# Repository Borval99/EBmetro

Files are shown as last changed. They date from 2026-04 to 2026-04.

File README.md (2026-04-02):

# EBmetro

## Descrizione

Il progetto riguarda la ricostruzione di un **misuratore di campi elettrici e magnetici (EBmetro)** ideato dal Prof. Francesco Dalla Valle.

Lo strumento è stato progettato per rendere **misurabili e osservabili**:

* intensità del campo elettrico e magnetico
* direzione
* verso

con l’obiettivo di fornire un supporto concreto alla comprensione dell’elettromagnetismo.

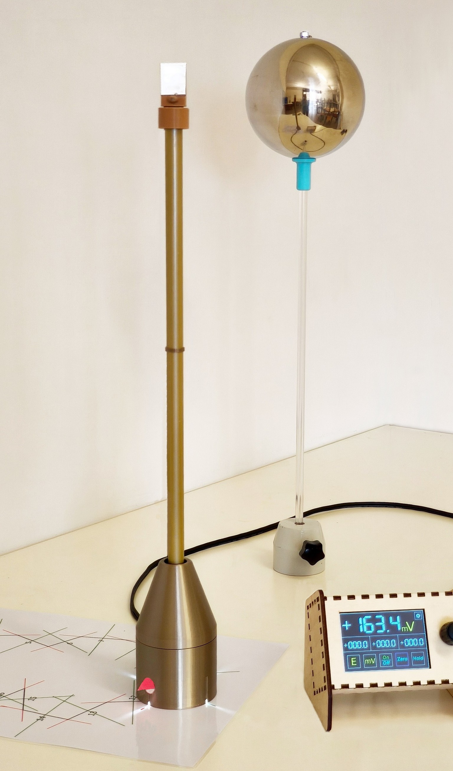
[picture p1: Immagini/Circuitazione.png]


---

## Obiettivo

L’EBmetro permette di verificare sperimentalmente:

* la circuitazione del campo elettrico lungo una linea chiusa
* la circuitazione del campo magnetico
* il fenomeno dell’induzione elettromagnetica

rendendo osservabili in modo diretto le prime tre equazioni di Maxwell.

---

## Struttura della repository

### /3D Model

Contiene i modelli dei case utilizzati per ospitare il microcontrollore e la scheda di acquisizione.

Sono presenti due principali varianti:

* versione per stampa 3D
* versione per taglio laser

La versione realizzata tramite intaglio laser consente una produzione più rapida e semplificata.

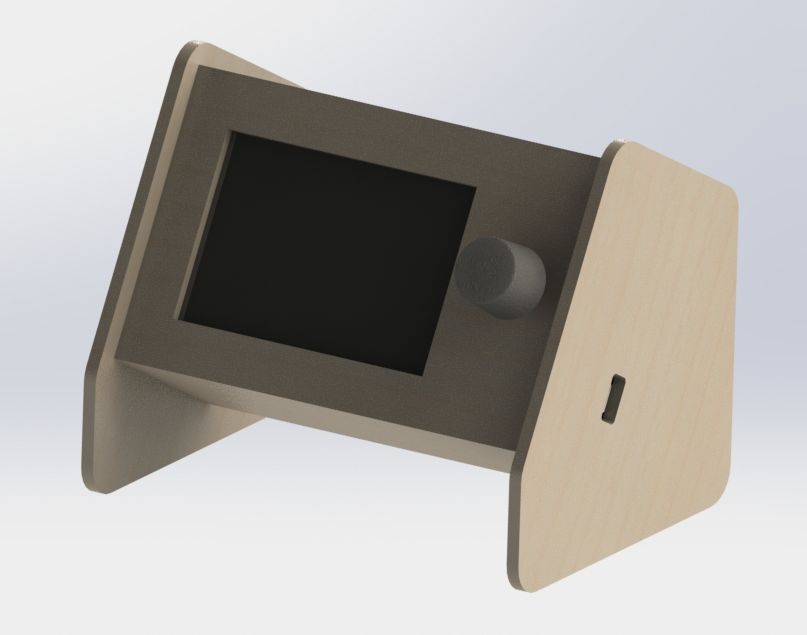
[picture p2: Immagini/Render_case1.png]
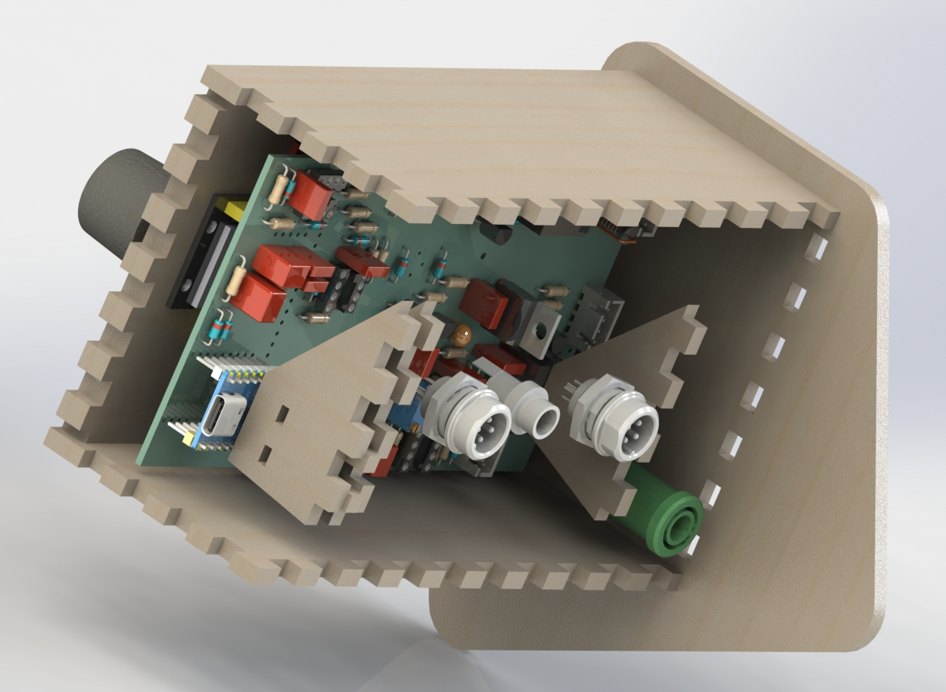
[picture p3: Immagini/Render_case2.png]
 

---

### /EBmetro

Contiene l’implementazione completa del dispositivo:

* schemi elettronici
* PCB
* firmware

Dove sono presenti le schede per l'EBmetro e per la base dell'EBmetro.

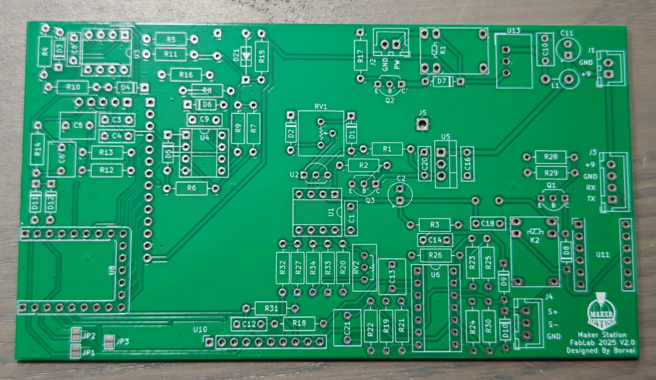
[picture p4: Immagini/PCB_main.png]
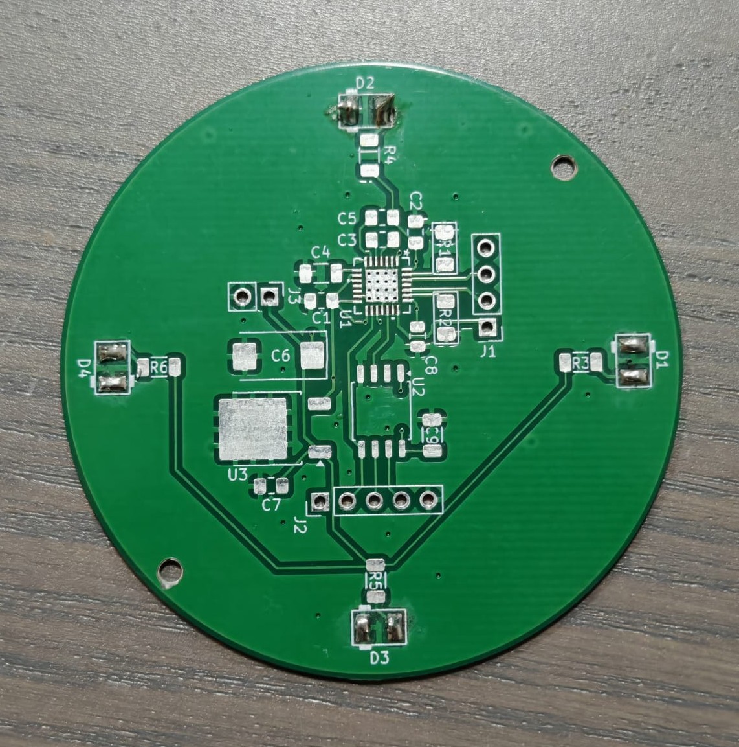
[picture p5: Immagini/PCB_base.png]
 

---

### /generatore

Contiene lo sviluppo di un generatore di rampe di corrente:

* schema elettronico
* firmware

Il generatore è in grado di fornire correnti fino a 30 A ed è utilizzato per pilotare bobine di Helmholtz.
Questo consente di generare campi magnetici controllati e misurare, tramite il sensore (“manico”), l’andamento della corrente indotta in un avvolgimento di dimensioni variabili.

---

## Descrizione del funzionamento

Il dispositivo consente la misura del campo elettrico o magnetico in funzione:

* della testina installata
* delle impostazioni software

L’elemento principale è una **testina rotante** dotata di contatti in oro, che ruota sul proprio asse.

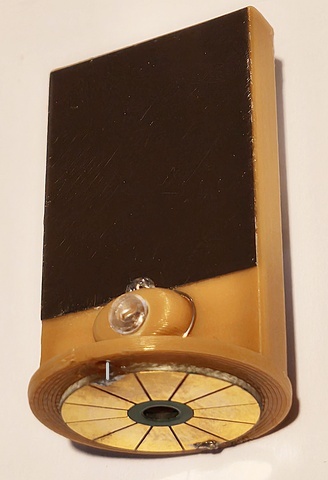
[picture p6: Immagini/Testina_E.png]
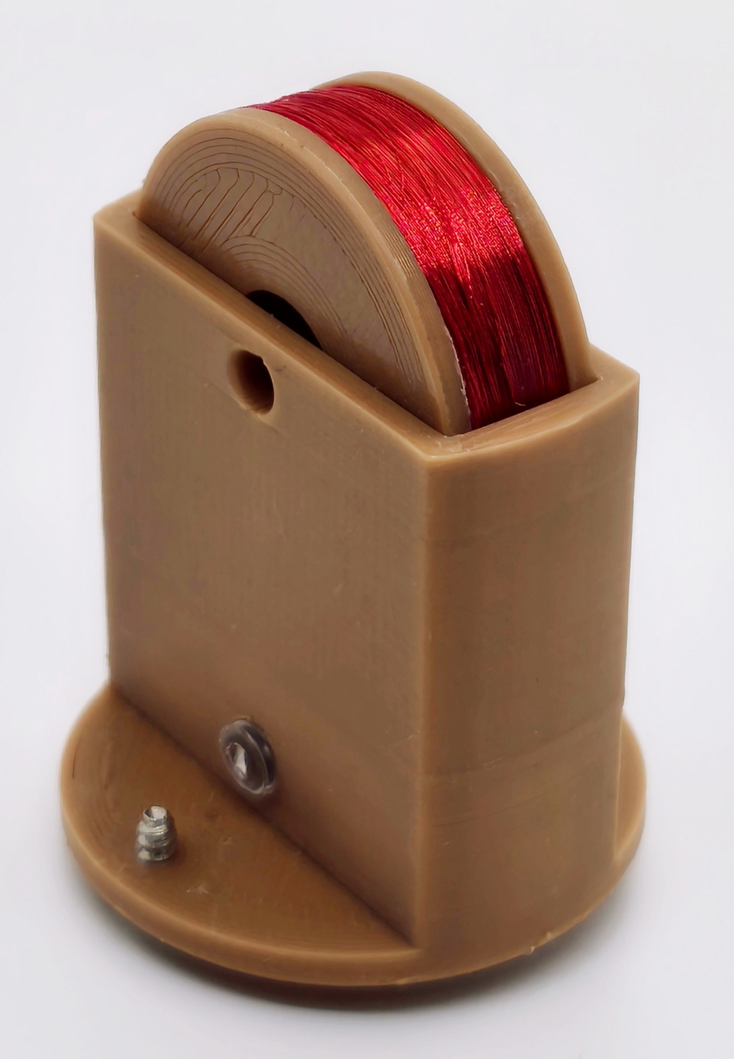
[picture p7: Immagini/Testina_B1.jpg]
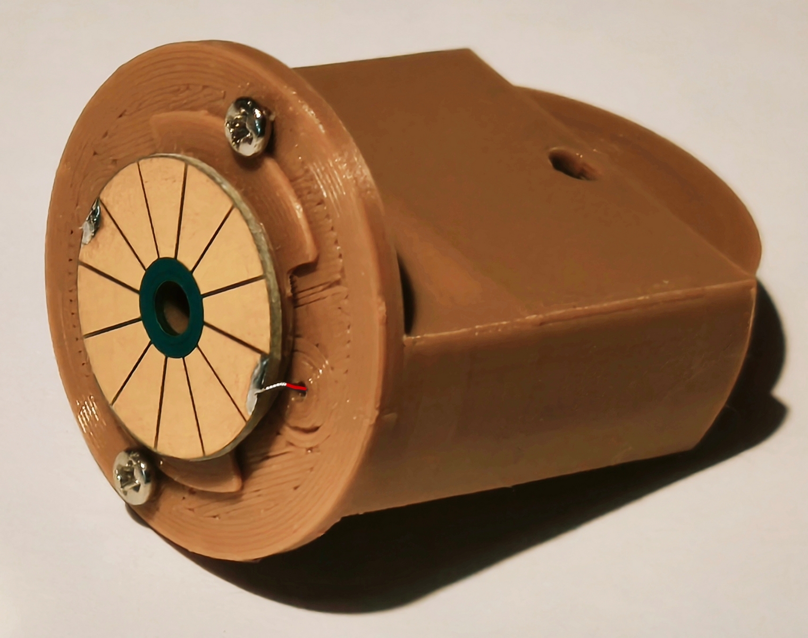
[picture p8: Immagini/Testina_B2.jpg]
  

I contatti sono stati realizzati tramite PCB, HASL con placcatura.

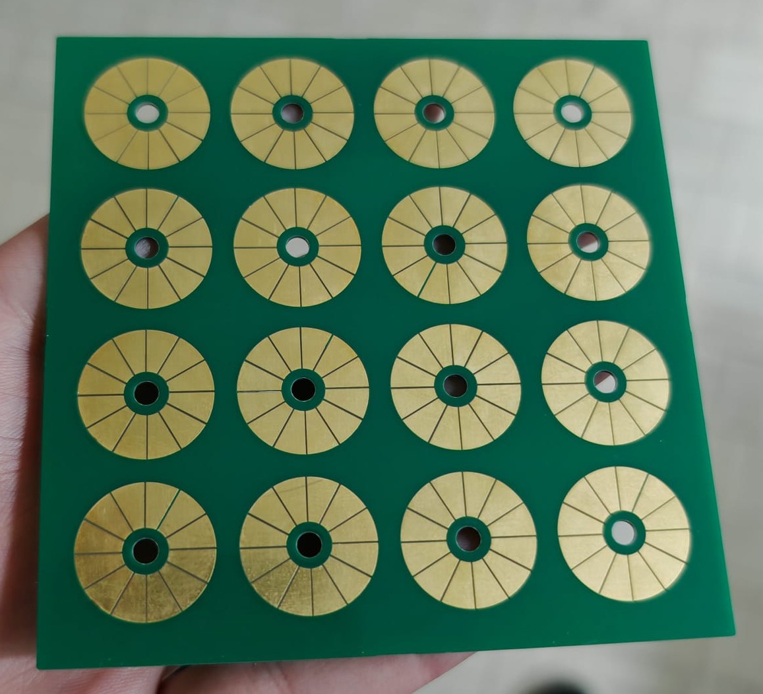
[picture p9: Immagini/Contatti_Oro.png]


Durante la rotazione, la testina entra in contatto con due **contatti striscianti**, permettendo l’acquisizione del segnale.

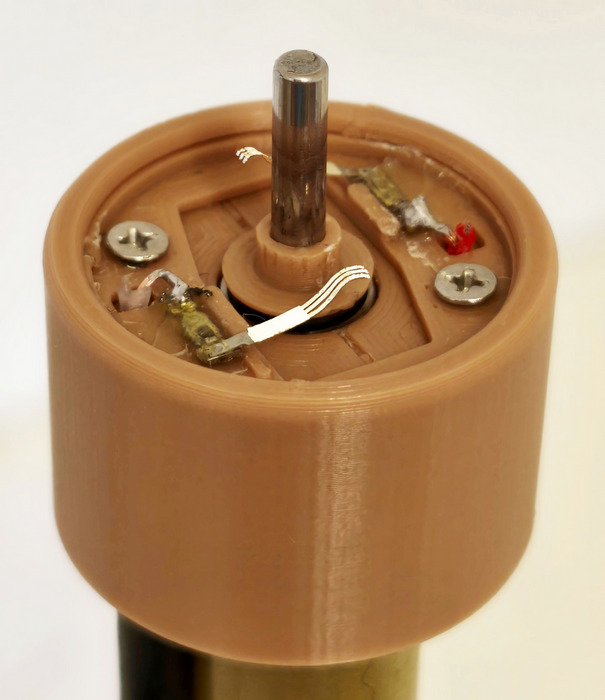
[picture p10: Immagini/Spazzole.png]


L’elaborazione del segnale avviene in un’unità separata dalla base, al fine di ridurre le interferenze sulla misura.

Nella base dell’EBmetro è possibile integrare:

* un motore brushless
* oppure un motore passo-passo

entrambi controllati da un microcontrollore ATtiny85 posizionato sotto la struttura.

L'EBmetro ha inoltre un Goniometro sulla propria base.

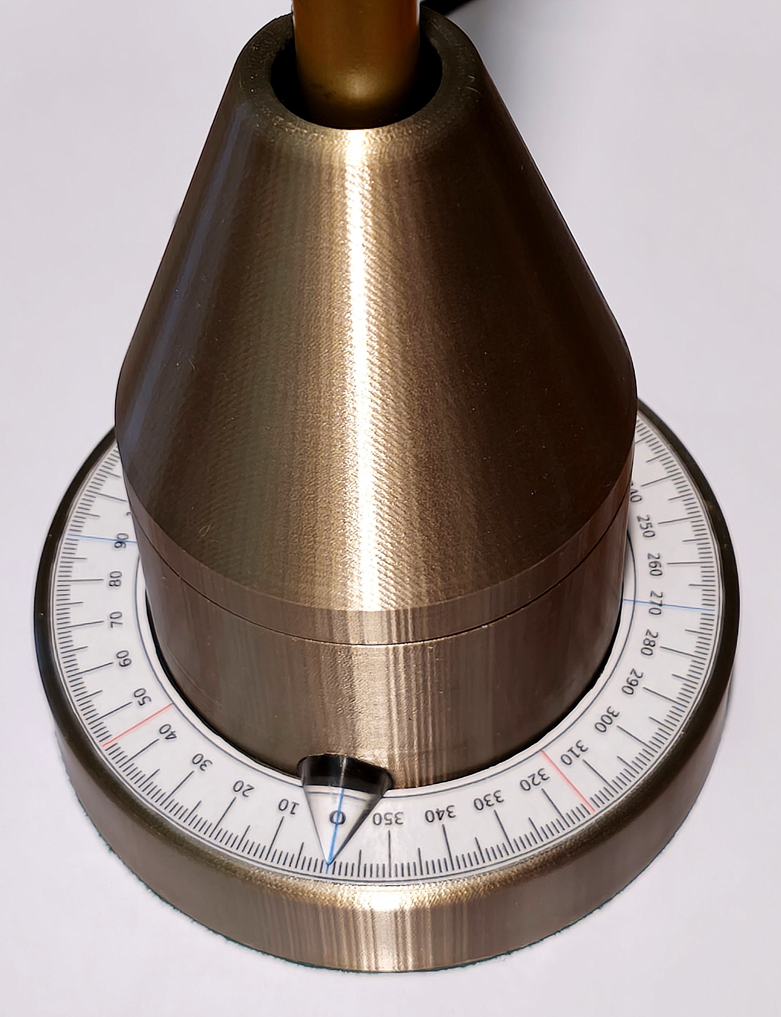
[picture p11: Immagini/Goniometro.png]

---

## Crediti

Ideato dal:

* Prof. Francesco Dalla Valle
* Prof. Giacomoni
* Prof. Cortesi

Sviluppo di questa versione:

* Enzo Cortesi
* Ing. Valerio Borghi
* FabLab Maker Station Bassa Romagna

---

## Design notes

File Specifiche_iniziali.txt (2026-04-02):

Filo:
Limitazione della corrente : Passo 2A, Max 30A (Passi con stabilizzazione Led Blink)
Tensione no limiti

Rampe:
Limitatore di corrente Fisso a 15A
Regolo in tensione 2-15V passo di massimo che si puo avere (Da stabilire all'inizio)
Vogliamo poter leggere corrente e tensione, realtime max min per ogni rampa

Onda trapezioidale, _/-\_ t1=t3=5s t2=t4=0.5s-5s
da ripetere 5 cicli alla pressione

Display 1.8p 128x160 Driver:st7735

Modalità:
-Filo
-Rampa
-Calibrazione? oppure settings in ogni pagina

Modaità Filo:
Mostra Tensione, Corrente
Passo attuale, passo prima e passo dopo
Cambio Modalità
Settings?

Modalità Rampe:
Mostra Tensione, Corrente, Max Min per Runtime
Onda Trapezoidale 
Tempi sotto l'onda, modificabili lampeggianti
Start
Un mini grafico della tensione? magari piu avanti

Generatore Classico: 
Dobbiamo mettere il display esterno,
Dia un impulso della Rampa al Misuratore della FEM

Misuratore della FEM:
Letture di qualche micro 
Schermo su cui scriverle
Offset Automatico / Manuale
Lettura precisa, accurato?

EBmetro
Alimentazione motore passo passo 20 step con driver
arduino nano 
Letture a mV

Misuratore di cariche

A parte a batterie 
Circuito campo elettrico

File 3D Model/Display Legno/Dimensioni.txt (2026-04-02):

"WFront"= 140mm
"HFront"= 80mm
"DFront"= 4mm
"WLeft"= 50mm
"HLeft"= 80mm
"DLeft"= 4mm
"WTop"= 140mm
"HTop"= 50mm
"DTop"= 4mm
"N_Denti_W"= 10
"N_Denti_H"= 7
"N_Denti_D"= 4
"HDistDenti"= "HFront" / "N_Denti_H"
"WDistDenti"= "WFront" / "N_Denti_W"
"DDistDenti"= "WLeft" / "N_Denti_D"
"HDenti"= "HDistDenti" / 2
"WDenti"= "WDistDenti" / 2
"DDenti"= "DDistDenti" / 2
"WDisplay"= 95mm
"HDisplay"= 61mm
"CEnc"= 7mm
"Display_to_Enc_W"= 11.5 + "CEnc" / 2
"Display_to_Dx"= 32mm
"Display_to_Top"= 10mm
"Display_to_Enc_H"= 24 + "CEnc" / 2
"DMask"= 3mm

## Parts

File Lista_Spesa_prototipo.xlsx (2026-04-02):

Si = |  |  |  | Lista della spesa
No = |  | Roba da compare al tecnomat =
In Lab = |  | Roba da comprare =
 | Da Acquistare | Generatore
 |  | Nome | Quantità | SIGLA | Prezzo I.I. | Link Acquisto | Link Datasheet | Note | Totale
 |  | DC-DC Converter Principale | 1 | ap-d5830a | 35 | Aliexpress (https://it.aliexpress.com/item/1005006873314722.html) | Datasheet (https://amsanelectronics.com/product/step-down-800w-30a-buck-converter-power-supply-penurun-tegangan-dc/) |  | 35
 |  | Alimentatore 24V 20A | 1 | RND 315-00017 | 109.8 | Distrelect (https://www.distrelec.it/it/alimentatore-montato-su-guida-din-ac-dc-94-24v-20a-480w-regolabile-rnd-rnd-315-00017/p/30151537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) | Datasheet (https://docs.rs-online.com/ba42/A700000011111373.pdf) | Era quello che costava meno | 109.8
 |  | Case PC + 3 ventole | 1 |  | 62.5 | Amazon (https://www.amazon.it/Mars-Gaming-MC-MASTER-Metal-Mesh-Ultrasilenziose/dp/B0BM4DSWJX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) |  | Da decidere | 62.5
 |  | Samd 21 Qt Py | 1 | Samd21 | 16 | Amazon (https://www.amazon.it/Adafruit-QT-Py-Scheda-sviluppo/dp/B09GZZF7BY?__mk_it_IT=%C3%85M%C3%85%C5%BD%C3%95%C3%91) |  |  | 16
 |  | MCP4725 | 1 | MCP4725 | 3 | Amazon (https://www.amazon.it/Jopto-Risoluzione-Fornitura-Compatibile-Raspberry/dp/B096Z6F4FB) | Datasheet (https://ww1.microchip.com/downloads/en/devicedoc/22039d.pdf) |  | 3
 |  | Connettore alta Potenza SA50 Pannello | 3 | SA50 Pannello | 3.14 | Aliexpress (https://it.aliexpress.com/item/1005005223111889.html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) | Datasheet (https://www.anen-connector.com/multipole-power-connectors-sa50sa502-2-product/) |  | 9.42
 |  | Pin per Connettore alta Potenza SA50 | 3 | SA50 PIN AWG6 | 0.6954 | CS (https://www.cselettronica.net/elettronica/connessione/conn-sa50-sb50-/pa1319-contatto-awg6-per-sa120.1.1.2444.gp.28132.uw) | Datasheet (https://www.anen-connector.com/multipole-power-connectors-sa50sa502-2-product/) |  | 2.0862
 |  | Connettore Display GX12-5Pin Maschio | 2 | GX12-5 | 0.7 | Amazon (https://www.amazon.it/QitinDasen-Aviazione-Connettore-Protettore-Cacciavite/dp/B07Y9VL1CT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) | Datasheet (https://renhotecpro2.b-cdn.net/wp-content/uploads/2022/01/GX-Series-Aviation-Connectors-Presentation-1.pdf) | Ki 8 +8 | 1.4
 |  | Resistenza shunt 40A 75mA | 1 | FL-2C 40A | 4.6 | Ebay (https://www.ebay.it/itm/164377654976?itmmeta=01J457QHX240EEKFACPEP4HRY8) |  | Sono indeciso tra 30A e 50A | 4.6
 |  | Ventole per pc | 2 |  | 5.5 | Amazon (https://www.amazon.it/Ventilatore-Silenzioso-Ottimizzata-Pressione-Confezione/dp/B07HC7P3HJ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) |  | Da decidere in base al case | 11
 |  | DC-DC Alimentazioni secondarie | 1 | LM2596 | 4.3 | CS (https://www.cselettronica.net/elettronica/alimentazione/convertitori-dc-dc/uscita-regolabile/2846-modulodcdc-dc-dc-uscita-1-5-35v-3a.1.1.2507.gp.22213.uw) |  |  | 4.3
 |  | Convertitore ADC 1115 | 1 | ADC1115 | 5.5 | Amazon (https://www.amazon.it/AZDelivery-Convertitore-ADS1115-Raspberry-Gratuito/dp/B07QHWLTTS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) | Datasheet (https://cdn-shop.adafruit.com/datasheets/ads1115.pdf) |  | 5.5
 |  | LMC6484 Quad OpAmp | 1 | LMC6484 | 2.5986 | CS (https://www.cselettronica.net/elettronica/attivi/integrati/integrati-a-z/integrati-lmc/integrato-lmc6484in-nopb.1.1.311.gp.3039.uw) | Datasheet (http://www.ti.com/lit/ds/symlink/lmc6484.pdf) |  | 2.5986
 |  | Sensore di Temperatura | 3 | LM35D | 1.5982 | CS (https://www.cselettronica.net/elettronica/attivi/integrati/integrati-a-z/integrati-lm/integrato-lm35dz-nopb.1.1.312.gp.11687.uw) | Datasheet (http://www.ti.com/lit/ds/symlink/lm35.pdf) |  | 4.7946
 |  | Componentistica varie | 1 |  | 15 | CS |  |  | 15
 |  | Relè per attivare/disattivare il DCDC | 1 | SYS1 | 0.7442 | CS (https://www.cselettronica.net/elettronica/commutazione/rele-elettromeccanici/rele-con-bobina-a-c-c-/bobina-a-5vdc/1-scambio/sys1-rele-5vdc-1-scambio.1.1.867.g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) | Datasheet (https://www.sanyourelay.ca/public/products/pdf/SYS1.pdf) |  | 0.7442
 |  | BC547 per Relè | 1 | BC547 | 0.061 | CS (https://www.cselettronica.net/elettronica/attivi/transistor/transistor/transistor-bc-/transistor-bc547b.1.1.750.gp.7309.uw) | Datasheet (https://www.mouser.it/datasheet/2/308/1/BC550_D-2310266.pdf) |  | 0.061
 |  | Reference Voltage 2.5 V | 1 | LM336Z-2.5 | 0.6466 | CS (https://www.cselettronica.net/elettronica/attivi/integrati/integrati-a-z/integrati-lm/integrato-lm336z-2-5-nopb.1.1.312.gp.18601.uw) | Datasheet (https://www.ti.com/lit/ds/symlink/lm136-2.5-n.pdf?HQS=dis-dk-null-digikeymode-dsf-pf-null-wwe&ts=1722377945944) |  | 0.6466
 |  | Cavo unipolare 16mm^2 | 2 |  | 2.5 |  |  |  | 5
 |  | Capicorda A3M6 per 16mm^2 | 5 | A3M6 | 0.2684 | CS (https://www.cselettronica.net/elettronica/connessione/terminali/terminali-preisolati/capicorda/a3m6-capicorda-non-isolato-a-6-4-b-11-5.1.1.2359.gp.19857.uw) |  |  | 1.342
 |  | 0,5 Ohm 100W 5% | 2 | HSC100R47J | 4 | Amazon (https://www.amazon.it/ETOPARS-Resistore-Alluminio-Resistenza-Adattatore/dp/B0BWXLP8VQ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) |  | Su Amazon costano la metà | 8
 |  | 0,10 Ohm 100W 5% | 3 | HSC100R10J | 4 | Amazon (https://www.amazon.it/PATIKIL-Alluminio-Involucro-Alloggiamento-Resistenza/dp/B0C6F3RVC3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) |  | Su Amazon costano la metà | 12
 |  | Dissipatore 250*70*28 | 2 |  | 17.995 | CS (https://www.cselettronica.net/elettronica/attivi/accessori/dissipatori/diss-a-pettine/sk4975sa-dissipatore-250x28-l-75-nero.1.1.114.gp.25388.uw) | Datasheet (https://www.fischerelektronik.de/web_fischer/en_GB/VA/SK4975SA/datasheet.xhtml?branch=heatsinks) |  | 35.99
 |  | Pasta Termica nano-grease 3g | 1 |  | 3.599 | CS (https://www.cselettronica.net/elettronica/attivi/accessori/paste-termoconduttive/pasta-termica-nano-grease-3gr.1.1.23.gp.11730.uw) |  |  | 3.599
 |  | Scheda PCB / Millefori 70*50 | 1 |  | 1 | CS |  |  | 1
 |  |  |  |  |  |  |  |  | 0
 |  | TOTALE |  |  |  |  |  |  | 355.3822
 |  | Wire
 |  | Nome | Quantità | SIGLA | Prezzo | Link Acquisto | Link Datasheet | Note | Totale
 |  | Tubo in ferro filettato | 3 |  | 7.9 | Tecnomat (https://www.tecnomat.it/it/tubo-ferro-zincato-3-8-100-cm-10008368/) |  |  | 23.7
 |  | Curve in ferro | 3 |  | 1.07 | Tecnomat (https://www.tecnomat.it/it/raccordo-ghisa-90-gomito-ff3-8-10035679/) |  |  | 3.21 | DA RIVEDERE
 |  | Connettore alta Potenza SA50 | 1 | SA50 | 0.9028 | CS (https://www.cselettronica.net/elettronica/connessione/conn-sa50-sb50-/sa50-supporto-per-contatti-2-vie-rosso-con-viti.1.1.2444.gp.21128.uw) | Datasheet (https://www.anen-connector.com/multipole-power-connectors-sa50sa502-2-product/) |  | 0.9028
 |  | Pin per Connettore alta Potenza SA50 | 1 | SA50 PIN AWG6 | 0.6954 | CS (https://www.cselettronica.net/elettronica/connessione/conn-sa50-sb50-/pa1319-contatto-awg6-per-sa120.1.1.2444.gp.28132.uw) | Datasheet (https://www.anen-connector.com/multipole-power-connectors-sa50sa502-2-product/) |  | 0.6954
 |  | Cavo unipolare 16mm^2 | 8 |  | 2.5 |  |  |  | 20
 |  | Struttura | 1 |  | 40 |  |  | Da decidere | 40
 |  | Gancio SA50 | 1 | SA50 Gancio | 1.0004 | CS (https://www.cselettronica.net/elettronica/connessione/conn-sa50-sb50-/pa112g1-maniglia-per-connettore-sa50-rossa-con-viti.1.1.2444.gp.28128.uw) | Datasheet (https://www.anen-connector.com/multipole-power-connectors-sa50sa502-2-product/) |  | 1.0004
 |  |  |  |  |  |  |  |  | 89.5086
 |  | Totale
 |  | Display
 |  | Nome | Quantità | SIGLA | Prezzo | Link Acquisto | Link Datasheet | Note | Totale
 |  | Display LCD tft 4'' | 1 |  | 20 | Amazon (https://www.amazon.it/LAFVIN-4-0-inch-TFT-Compatible/dp/B0CQ87KN3Q?__mk_it_IT=%C3%85M%C3%85%C5%BD%C3%95%C3%91) |  |  | 20
 |  | Arduino MKR Zero | 1 | Arduino MKR Zero | 20 | Arduino Store (https://store.arduino.cc/collections/boards-modules/products/arduino-mkr-zero-i2s-bus-sd-for-sound-music-digital-audio-data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) | Datasheet (https://docs.arduino.cc/resources/datasheets/ABX00023-datasheet.pdf) | Si può cambiare con qualcosa da meno | 20
 |  | Modulo Encoder KY040 | 1 | KY040 | 2.0008 | CS (https://www.cselettronica.net/ky040-modulo-encoder.1.0.2531.gp.23741.uw) |  |  | 2.0008
 |  | Scheda PCB / Millefori 70*50 | 1 |  | 1 | CS |  |  | 1
 |  | Connettore Display GX12-5Pin Maschio | 1 | GX12-5 | 0.7 | Amazon (https://www.amazon.it/QitinDasen-Aviazione-Connettore-Protettore-Cacciavite/dp/B07Y9VL1CT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) | Datasheet (https://renhotecpro2.b-cdn.net/wp-content/uploads/2022/01/GX-Series-Aviation-Connectors-Presentation-1.pdf) | Su Amazon costano la metà | 0.7
 |  | Connettore Display GX12-5Pin Femmina | 2 | GX12-5 | 0.7 | Amazon (https://www.amazon.it/QitinDasen-Aviazione-Connettore-Protettore-Cacciavite/dp/B07Y9VL1CT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) | Datasheet (https://renhotecpro2.b-cdn.net/wp-content/uploads/2022/01/GX-Series-Aviation-Connectors-Presentation-1.pdf) | Su Amazon costano la metà | 1.4
 |  | Cavo 5 poli Morbido | 2 |  | 2 |  |  | Da decidere | 4
 |  | Connettori in plastica per connesioni interne | 1 |  | 1 |  |  |  | 1
 |  | Manopola 22 più tappo blu | 1 |  | 1 | CS |  |  | 1
 |  | Totale |  |  |  |  |  |  | 51.1008
 |  | Manico
 |  | Nome | Quantità | SIGLA | Prezzo | Link Acquisto | Link Datasheet | Note | Totale
 |  | Connettore manico GX12-5Pin Maschio | 1 | GX12-5 | 0.7 | Amazon (https://www.amazon.it/QitinDasen-Aviazione-Connettore-Protettore-Cacciavite/dp/B07Y9VL1CT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) | Datasheet (https://renhotecpro2.b-cdn.net/wp-content/uploads/2022/01/GX-Series-Aviation-Connectors-Presentation-1.pdf) | Su Amazon costano la metà | 0.7
 |  | Connettore manico GX12-5Pin Femmina | 2 | GX12-5 | 0.7 | Amazon (https://www.amazon.it/QitinDasen-Aviazione-Connettore-Protettore-Cacciavite/dp/B07Y9VL1CT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) | Datasheet (https://renhotecpro2.b-cdn.net/wp-content/uploads/2022/01/GX-Series-Aviation-Connectors-Presentation-1.pdf) | Su Amazon costano la metà | 1.4
 |  | Cavo 5 poli Morbido | 3 |  | 2 |  |  | Da decidere | 6
 |  | Scheda PCB / Millefori 30*40 | 1 |  | 1 | CS |  |  | 1
 |  | Convertitore ADC 1115 | 1 | ADC1115 | 5.5 | Amazon (https://www.amazon.it/AZDelivery-Convertitore-ADS1115-Raspberry-Gratuito/dp/B07QHWLTTS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) | Datasheet (https://cdn-shop.adafruit.com/datasheets/ads1115.pdf) |  | 5.5
 |  | LMC6484 Quad OpAmp | 1 | LMC6484 | 2.5986 | CS (https://www.cselettronica.net/elettronica/attivi/integrati/integrati-a-z/integrati-lmc/integrato-lmc6484in-nopb.1.1.311.gp.3039.uw) | Datasheet (http://www.ti.com/lit/ds/symlink/lmc6484.pdf) | Per creare lo zero | 2.5986
 |  | Amplif da Banco AD623ANZ | 1 | AD623ANZ | 6.954 | CS (https://www.cselettronica.net/elettronica/attivi/integrati/integrati-a-z/integrati-ad/integrato-ad623anz.1.1.744.gp.23999.uw) | Datasheet (https://www.analog.com/media/en/technical-documentation/data-sheets/ad623.pdf) | Al posto di questo un adc che fa tutto ma costa 20 | 6.954
 |  | Teste di racambio del Manico | 3 |  | 10 |  |  | Non so quanto possano costare | 30
 |  | Arduino nano | 1 |  | 8 |  |  | Ci mettiamo un nano per ora | 8
 |  | Componentistica varie | 1 |  | 5 | CS |  |  | 5
 |  | Totale |  |  |  |  |  |  | 67.1526
 |  | Ebmetro
 |  | Nome | Quantità | SIGLA | Prezzo | Link Acquisto | Link Datasheet | Note | Totale
 |  | Arduino Nano | 1 |  | 10 | Arduino Store (https://store.arduino.cc/products/arduino-nano) | Datasheet (https://ww1.microchip.com/downloads/en/DeviceDoc/Atmel-7810-Automotive-Microcontrollers-ATmega328P_Datasheet.pdf) | Su Amazon costa meno | 10
 |  | Batterie al litio | 2 |  | 5 |  |  | Da decidere | 10
 |  | Circuito di ricarica | 1 |  | 3 |  |  | Da decidere | 3
 |  | Connettore manico GX12-5Pin Maschio | 2 | GX12-5 | 0.7 | Amazon (https://www.amazon.it/QitinDasen-Aviazione-Connettore-Protettore-Cacciavite/dp/B07Y9VL1CT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) | Datasheet (https://renhotecpro2.b-cdn.net/wp-content/uploads/2022/01/GX-Series-Aviation-Connectors-Presentation-1.pdf) | Su Amazon costano la metà | 1.4
 |  | Connettore manico GX12-5Pin Femmina | 2 | GX12-5 | 0.7 | Amazon (https://www.amazon.it/QitinDasen-Aviazione-Connettore-Protettore-Cacciavite/dp/B07Y9VL1CT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) | Datasheet (https://renhotecpro2.b-cdn.net/wp-content/uploads/2022/01/GX-Series-Aviation-Connectors-Presentation-1.pdf) | Su Amazon costano la metà | 1.4
 |  | Cavo 5 poli Morbido | 2 |  | 2 |  |  | Da decidere | 4
 |  | Convertitore ADC 1115 | 1 | ADC1115 | 5.5 | Amazon (https://www.amazon.it/AZDelivery-Convertitore-ADS1115-Raspberry-Gratuito/dp/B07QHWLTTS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) | Datasheet (https://cdn-shop.adafruit.com/datasheets/ads1115.pdf) |  | 5.5
 |  | Componentistica varie | 1 |  | 5 | CS |  |  | 5
 |  | Componentistica di Enzo | 1 |  | 50 | CS |  | Da decidere | 50 | Discutibili
 |  | Display tft 1,8'' con driver ST3735 | 1 |  | 8.052 | CS |  | Da decidere | 8.052
 |  | Totale |  |  |  |  |  |  | 98.352
 |  | Misuratore di Carche
 |  | Nome | Quantità | SIGLA | Prezzo | Link Acquisto | Link Datasheet | Note | Totale
 |  | Arduino Nano | 1 |  | 10 | Arduino Store (https://store.arduino.cc/products/arduino-nano) | Datasheet (https://ww1.microchip.com/downloads/en/DeviceDoc/Atmel-7810-Automotive-Microcontrollers-ATmega328P_Datasheet.pdf) | Su Amazon costa meno | 10
 |  | Batterie al litio | 2 |  | 5 |  |  | Da decidere | 10
 |  | Circuito di ricarica | 1 |  | 6 |  |  | Da decidere | 6
 |  | Convertitore ADC 1115 | 1 | ADC1115 | 5.5 | Amazon (https://www.amazon.it/AZDelivery-Convertitore-ADS1115-Raspberry-Gratuito/dp/B07QHWLTTS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) | Datasheet (https://cdn-shop.adafruit.com/datasheets/ads1115.pdf) |  | 5.5
 |  | Componentistica varie | 1 |  | 5 | CS |  |  | 5
 |  | Componentistica di Enzo | 1 |  | 30 | CS |  | Da decidere | 30
 |  | Display tft 1,8'' con driver ST3735 | 1 |  | 8.052 | CS |  | Da decidere | 8.052
 |  | Totale |  |  |  |  |  |  | 74.552
 |  | Totale di tutto |  |  |  |  |  |  | 736.0482
 |  | COMPONENTI DA PROVARE
 |  | Attiny85 module | 1 | ATTiny85 | 12 | Amazon (https://www.amazon.it/Aihasd-Digispark-Kickstarter-ATTINY85-sviluppo/dp/B07439SSQV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) |  |  | 12
 |  | Adattatori | 1 |  | 8 | Amazon (https://www.amazon.it/Gebildet-3-3V-5V-Convertitore-bidirezionale-confezione/dp/B07RY15XMJ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) |  |  | 8
 |  | RP2040 | 1 |  | 10 | Amazon (https://www.amazon.it/XTVTX-microcontrollore-RP2040-Zero-intestazione-applicazioni/dp/B0BCVW5YKK/) |  |  | 10

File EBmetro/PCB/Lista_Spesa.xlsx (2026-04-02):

Reference | Value | Qty
C1,C3,C4,C8,C9,C14,C15,C18 | 100n | 8
C2,C17 | 15u | 2
C5,C6,C7,C13,C19 | 1u | 5
C10,C11 | 1m | 2
C12 | 15n | 1
D1,D2,D3,D4,D5,D6,D7,D8,D9,D10,D11,D12 | 1N4148 | 12
DZ1 | 2.5V Zener 1N5222B | 1
J1,J2 | Conn_01x02 | 2
J3 | Conn_01x04 | 1
J4 | Conn_01x03 | 1
K1 | SYS1 | 1
K2 | TIANBO-HJR-4102-L | 1
Q1,Q2,Q3 | BC547B | 3
R1 | 2k4 | 1
R2,R18 | 100 | 2
R3 | 1k | 1
R4,R6,R8,R10 | 3.3K | 4
R5,R7,R9,R11 | 33k | 4
R12 | 330k | 1
R13,R14,R17,R29,RV1 | 10k | 5
R15 | 150 | 1
R16,R28 | 470 | 2
R19 | 220k | 1
R20,R21,R22,R23,R24,R26 | 45.3k, 1% | 6
R25 | 4.53k, 1% | 1
R27 | 15k | 1
R30 | 10M | 1
R31 | 18K | 1
U1,U3,U4,U6,U7 | MCP602 | 5
U2 | LM336Z25 | 1
U5,U9 | ~ | 2
U8 | RP2040-ZERO | 1
U10 | Adafruit ADS1115 | 1
U11 | Level Shifter CYT1076 | 1
U12 | Encoder KY-040 | 1

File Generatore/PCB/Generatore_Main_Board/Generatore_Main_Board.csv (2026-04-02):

Reference | Value
C1 | 100n
C2 | 10n
C3 | 100n
C4 | 10n
C5 | 100n
C6 | 10n
C7 | 100n
C8 | 100n
C9 | 100n
D1 | 1N4148
D2 | 1N4148
D3 | 1N4148
D4 | 1N4148
D5 | 1N4148
D6 | 1N4148
D7 | 1N4148
D8 | 1N4148
D9 | 1N4148
D10 | 1N4148
D11 | 1N4148
D12 | 1N4148
D13 | 1N4148
J1 | Conn_01x04
J2 | Conn_01x04
J3 | Conn_01x02
J4 | Conn_01x03
J5 | Conn_01x03
J6 | Conn_01x03
J7 | Conn_01x02
J8 | Conn_01x03
J9 | Conn_01x02
J10 | Conn_01x02
J11 | Conn_01x02
J12 | Conn_01x02
J13 | Presa IEC pannello
J14 | Alimentatore 230Vac/12Vdc
J15 | 13V_VDD_VENTOLE
J16 | Conn_01x02
K1 | SANYOU SYS1-S-112L
Q1 | BC547B
Q2 | 2N7000
Q3 | 2N7000
Q4 | 2N7000
Q5 | 2N7000
Q6 | BC547B
R1 | 4k7
R2 | 4k7
R3 | 4k7
R4 | 4k7
R5 | 4k7
R6 | 100R
R7 | 10k
R8 | 10k
R9 | 1k
R10 | 2k4
R11 | 27k
R12 | 3k
R13 | 100R
R14 | 100R
R15 | 14k7 1%
R16 | 14k7 1%
R17 | 45k3 1%
R18 | 45k3 1%
R19 | 4k7
R20 | 4k7
R21 | 4k7
R22 | 4k7
R23 | 10k
R24 | 1k2
R25 | 10k
R26 | 10k
RV1 | 10k
RV2 | 10k
U1 | Adafruit ADS1115
U2 | Adafruit ADS1115
U3 | Level Shifter CYT1076
U4 | Level Shifter CYT1076
U5 | MCP4725 breakout module
U6 | LM336Z5
U7 | LM35-LP
U8 | LMC6484
U9 | MCP602
U10 | LM336Z25
U11 | MCP602
U12 | RP2040-ZERO
U13 | DCDC_Converter 3,2-40V/1,25-35V

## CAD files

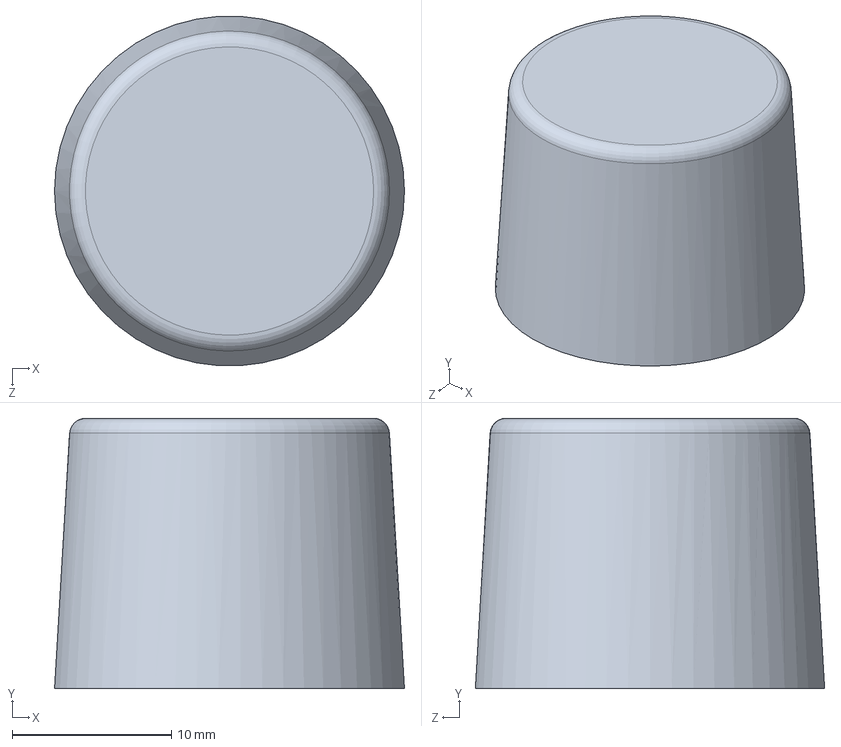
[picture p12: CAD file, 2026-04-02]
3D Model/Display Legno/Manopola.SLDPRT
22.0 x 17.0 x 22.0 mm

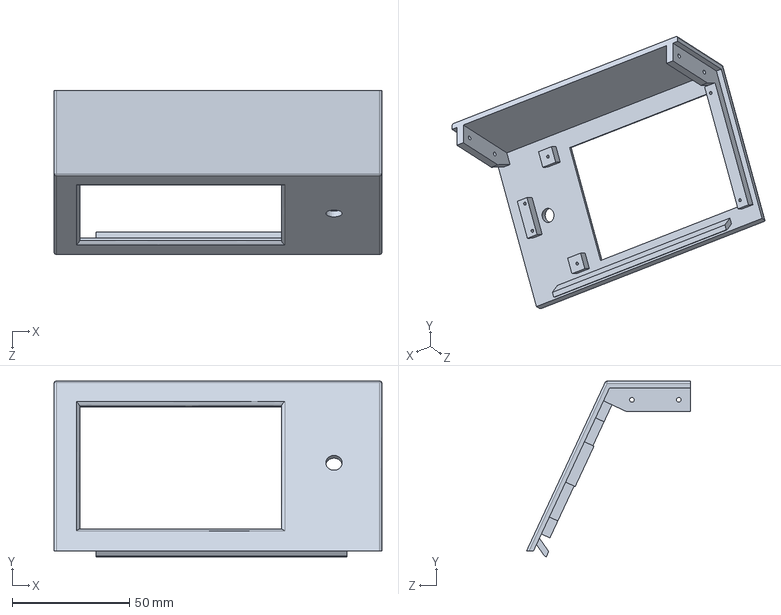
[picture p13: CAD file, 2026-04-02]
3D Model/Display/Case_Facciata.SLDPRT
140.0 x 75.0 x 70.0 mm

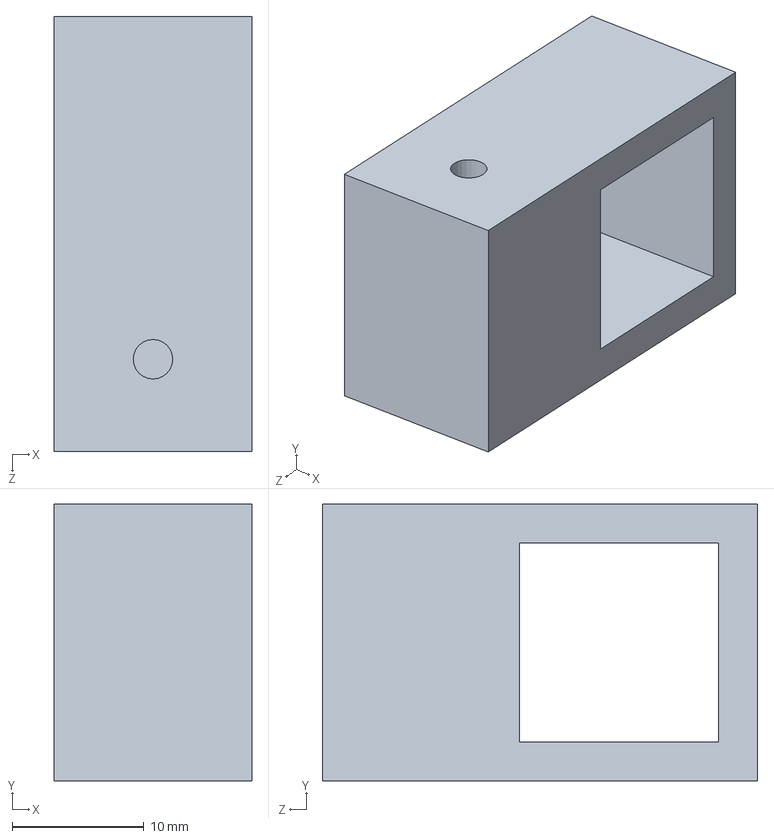
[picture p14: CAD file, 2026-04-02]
3D Model/Manico/STL/Supporto_1.SLDPRT
15.0 x 21.0 x 33.0 mm

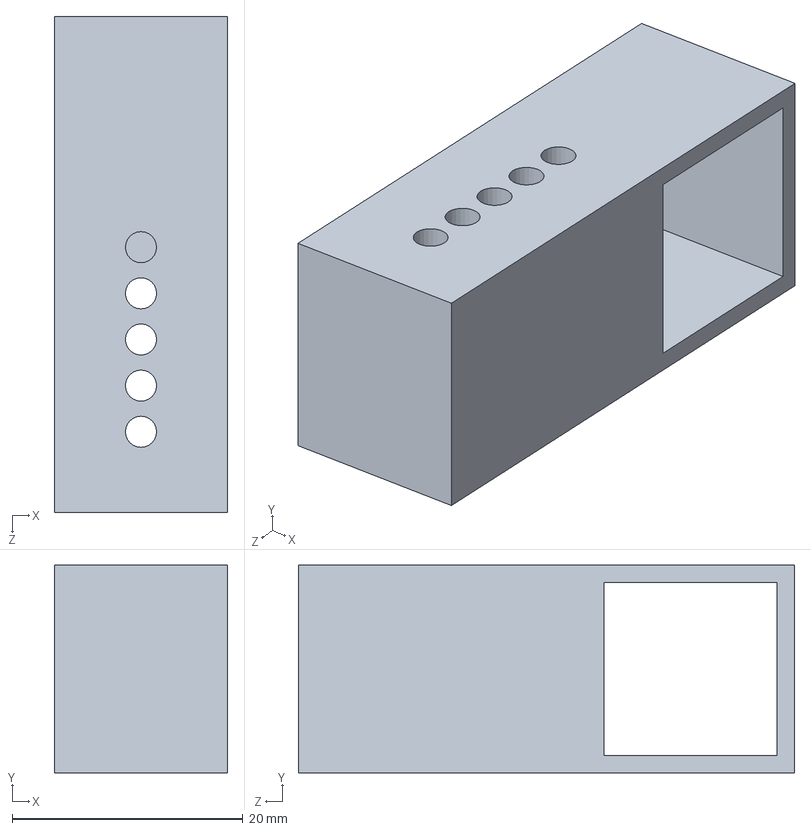
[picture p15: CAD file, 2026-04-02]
3D Model/Manico/Supporto_5.SLDPRT
15.0 x 18.0 x 43.0 mm

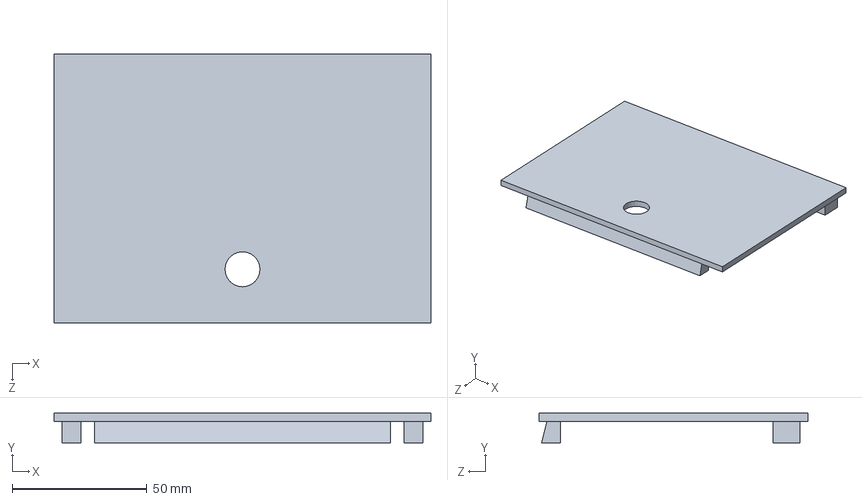
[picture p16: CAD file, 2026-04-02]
3D Model/Display/Case_Retro.SLDPRT
140.0 x 11.0 x 100.0 mm

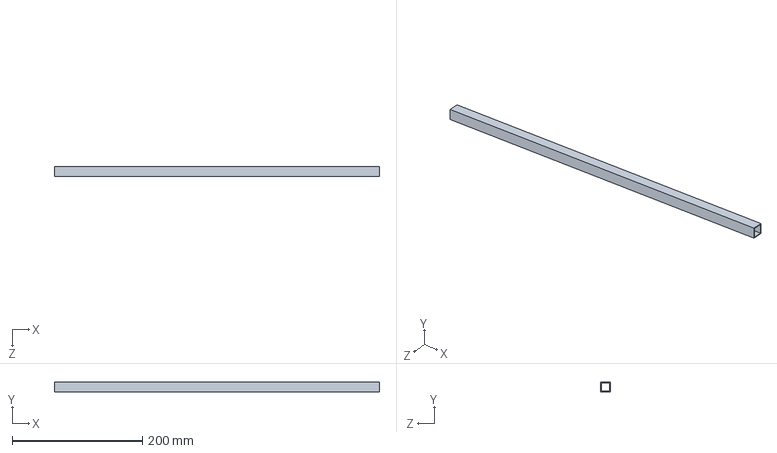
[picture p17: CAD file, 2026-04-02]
3D Model/Manico/Profilato_15_15.SLDPRT
500.0 x 15.0 x 15.0 mm

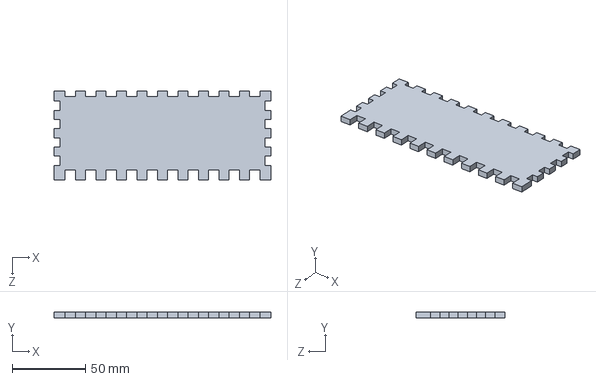
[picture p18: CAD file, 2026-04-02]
3D Model/Display Legno/Top.SLDPRT
148.0 x 4.00 x 61.0 mm

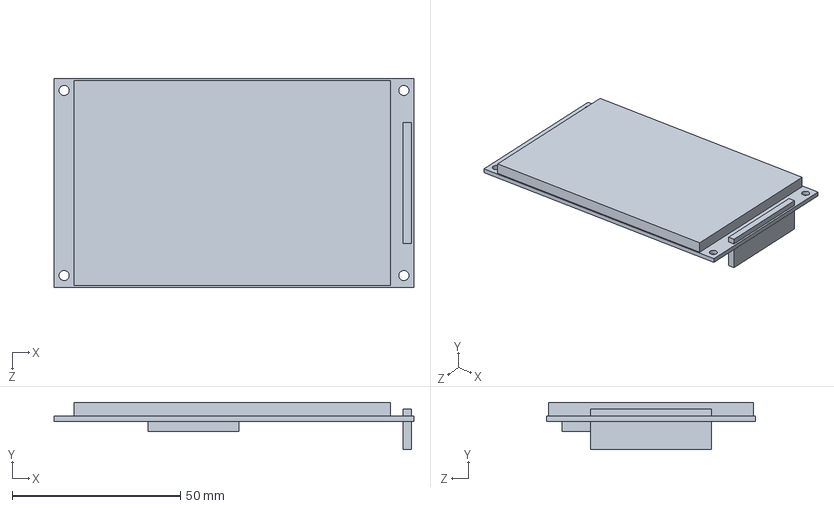
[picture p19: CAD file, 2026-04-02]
3D Model/Display/Display.SLDPRT
107.0 x 14.0 x 62.0 mm

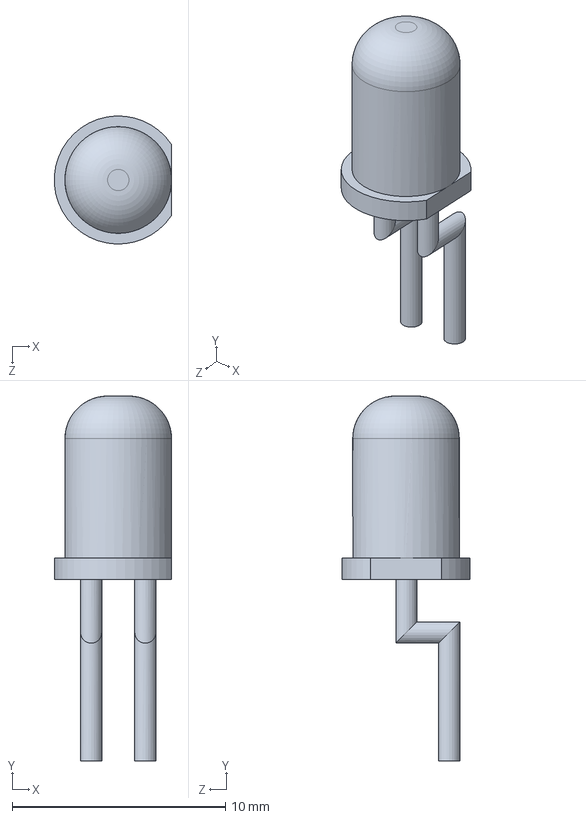
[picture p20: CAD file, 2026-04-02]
3D Model/EBmetro Base/LED.SLDPRT
5.49 x 17.1 x 6.00 mm

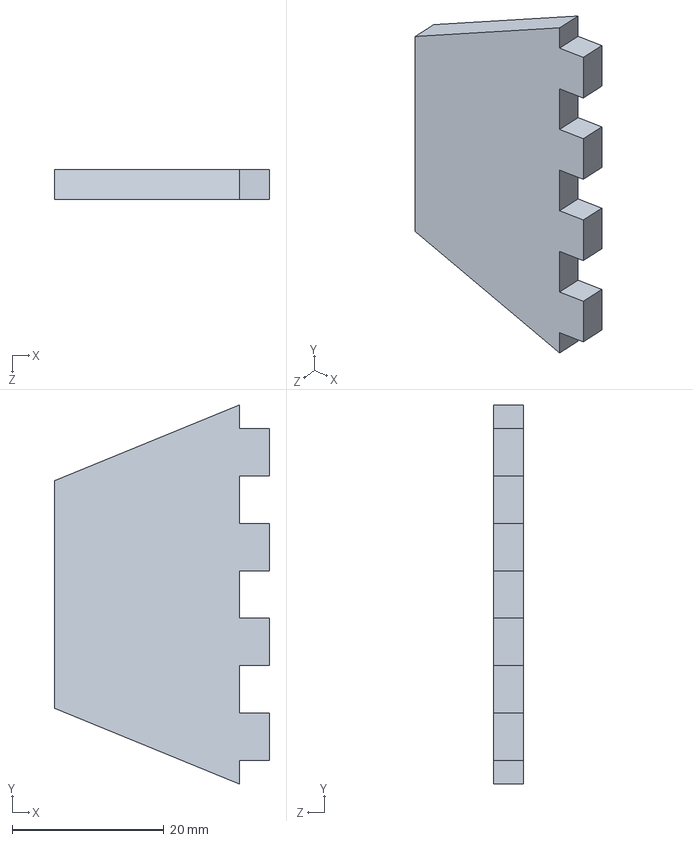
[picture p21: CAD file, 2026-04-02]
3D Model/Display Legno/Supporto.SLDPRT
28.4 x 50.0 x 4.00 mm

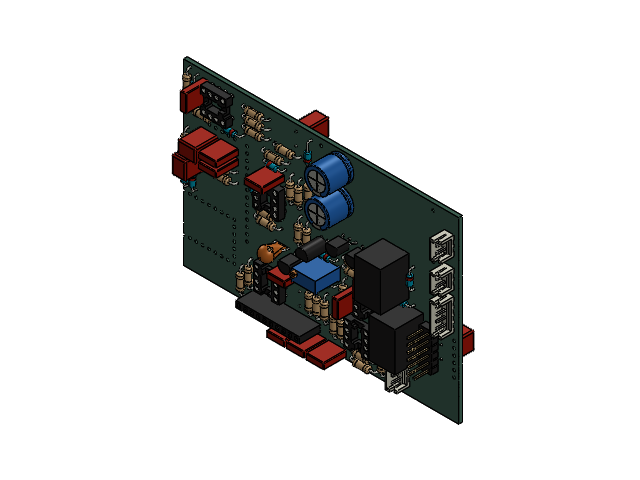
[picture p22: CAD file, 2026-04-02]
3D Model/Display_EBmetro.SLDASM
R_Axial_DIN0207_L6.3mm_D2.5mm_P10.16mm_Horizontal.step x 31
C_Rect_L7.2mm_W2.5mm_P5.00mm_FKS2_FKP2_MKS2_MKP2.step x 10
DIP-8_W7.62mm_Socket.step x 5
D_DO-35_SOD27_P7.62mm_Horizontal.step x 12
TO-92L_Inline_Wide.step
PinSocket_1x10_P2.54mm_Vertical.step
JST_EH_B2B-EH-A_1x02_P2.50mm_Vertical.step x 2
PinHeader_2x06_P2.54mm_Vertical.step
C_Rect_L7.2mm_W5.5mm_P5.00mm_FKS2_FKP2_MKS2_MKP2.step x 5
Relay_SPDT_HJR-4102.step x 2
TO-92_Inline_Wide.step x 3
JST_EH_B3B-EH-A_1x03_P2.50mm_Vertical.step
CP_Radial_D10.0mm_P5.00mm.step x 2
JST_EH_B4B-EH-A_1x04_P2.50mm_Vertical.step
Potentiometer_Bourns_3296W_Vertical.step
CP_Radial_Tantal_D5.5mm_P5.00mm.step
D_DO-35_SOD27_P10.16mm_Horizontal.step
Display_EBmetro_PCB.step

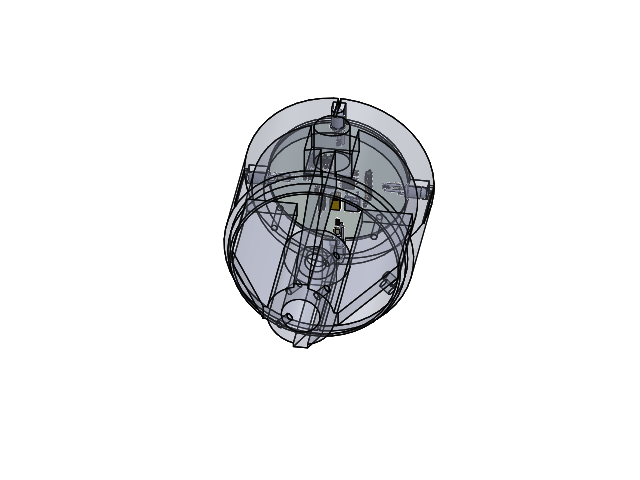
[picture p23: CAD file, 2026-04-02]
3D Model/EBmetro Base/Base.SLDASM
LED x 4
Base
Base 1.18.1.STEP
LED_1210_3225Metric.STEP x 4
C_0805_2012Metric.STEP x 6
SOIC-8_5.3x5.3mm_P1.27mm.STEP
R_1206_3216Metric.STEP x 6
PinHeader_1x02_P2.54mm_Vertical.STEP
C_1206_3216Metric.STEP x 2
PinHeader_1x05_P2.54mm_Vertical.STEP
PinHeader_1x04_P2.54mm_Vertical.STEP
CP_EIA-7343-31_Kemet-D.STEP
Base_PCB.STEP

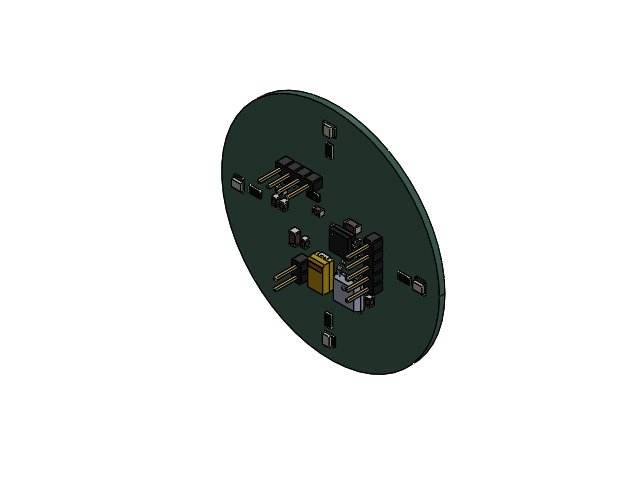
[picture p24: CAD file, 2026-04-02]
3D Model/EBmetro Base/PIPPO.SLDASM
Base 1.18.1.STEP
LED_1210_3225Metric.STEP x 4
C_0805_2012Metric.STEP x 6
SOIC-8_5.3x5.3mm_P1.27mm.STEP
R_1206_3216Metric.STEP x 6
PinHeader_1x02_P2.54mm_Vertical.STEP
C_1206_3216Metric.STEP x 2
PinHeader_1x05_P2.54mm_Vertical.STEP
PinHeader_1x04_P2.54mm_Vertical.STEP
CP_EIA-7343-31_Kemet-D.STEP
Base_PCB.STEP

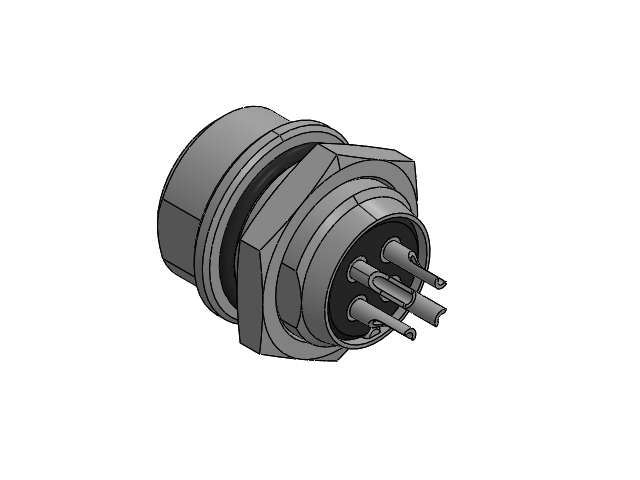
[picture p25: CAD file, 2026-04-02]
3D Model/Display/GX12-4_Maschio.SLDASM
Body003.step x 4
Body.step
Body001.step
Body002.step
Body004.step

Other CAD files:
3D Model/Display/Display_EBmetro.SLDASM
3D Model/Display/QT-PY.SLDASM
3D Model/Display Legno/PCBB.SLDASM
3D Model/Display Legno/Back.SLDPRT
3D Model/Display Legno/Boccola_4.SLDPRT
3D Model/Display Legno/DXF/Back.DXF
3D Model/Display Legno/DXF/Front.DXF
3D Model/Display Legno/DXF/LeftV2.DXF
3D Model/Display Legno/DXF/LeftV2_62.DXF
3D Model/Display Legno/DXF/LeftV3.DXF
3D Model/Display Legno/DXF/Mask.DXF
3D Model/Display Legno/DXF/Pirulino.DXF
3D Model/Display Legno/DXF/RightV2.DXF
3D Model/Display Legno/DXF/RightV2_62.DXF
3D Model/Display Legno/DXF/RightV3.DXF
3D Model/Display Legno/DXF/Supporto.DXF
3D Model/Display Legno/DXF/Supporto2.DXF
3D Model/Display Legno/DXF/Top.DXF
3D Model/Display Legno/Display.SLDPRT
3D Model/Display Legno/Encoder.SLDPRT
3D Model/Display Legno/Front.SLDPRT
3D Model/Display Legno/Left.SLDPRT
3D Model/Display Legno/LeftV2.SLDPRT
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

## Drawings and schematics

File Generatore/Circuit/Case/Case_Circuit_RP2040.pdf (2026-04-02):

# 230VAC ¹²V_VDD_OUT 5V_VDD_OUT

# CASE

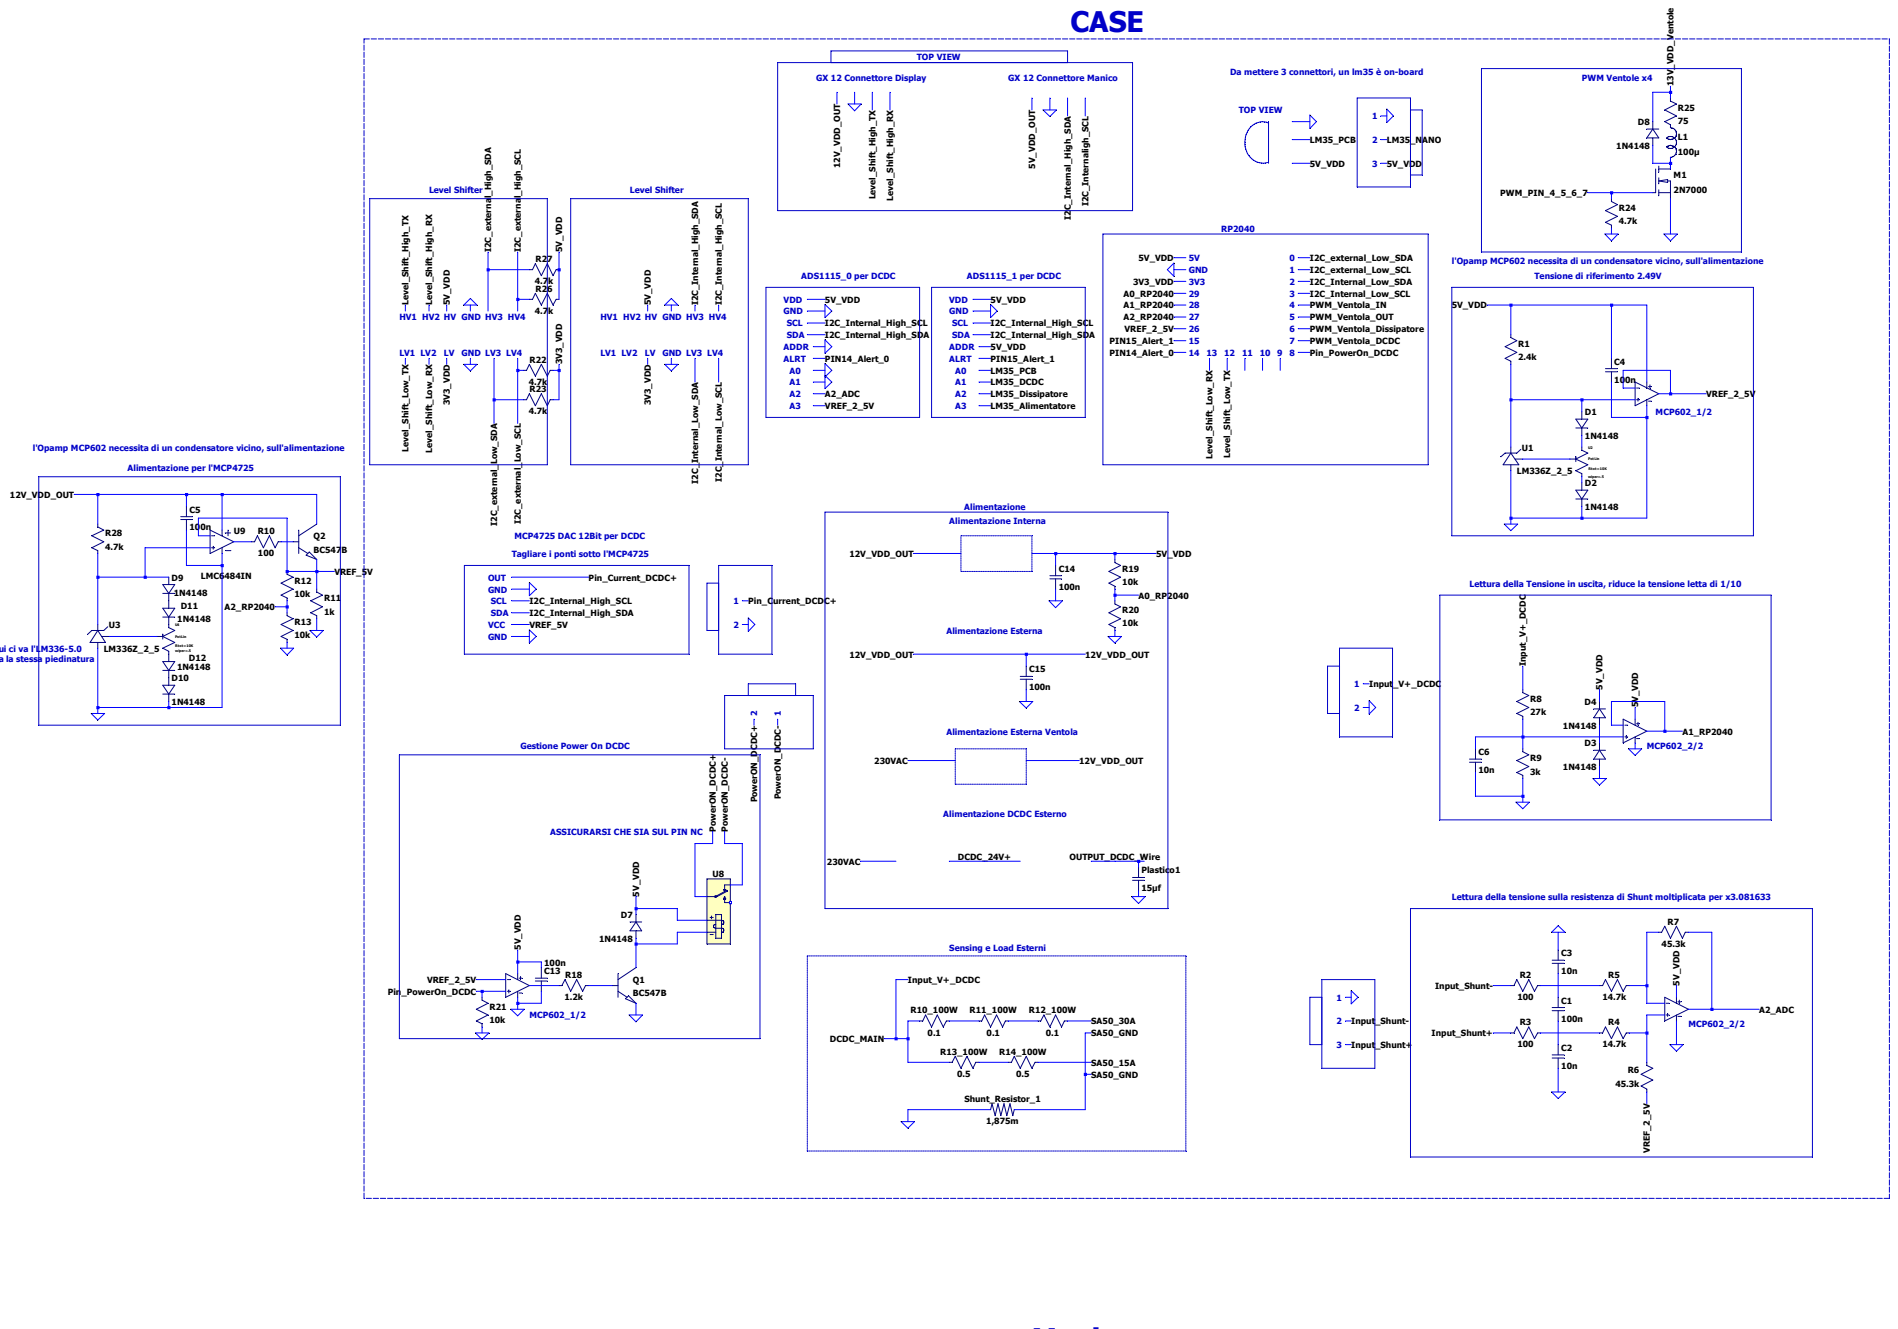
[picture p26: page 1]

Da mettere 3 connettori, un lm35 è on-board

l'Opamp MCP602 necessita di un condensatore vicino, sull'alimentazione
VREF_2_5V

Lettura della Tensione in uscita, riduce la tensione letta di 1/10

Qui ci va l'LM336-5.0
Ha la stessa piedinatura

Gestione Power On DCDC

ASSICURARSI CHE SIA SUL PIN NC

Lettura della tensione sulla resistenza di Shunt moltiplicata per x3.081633

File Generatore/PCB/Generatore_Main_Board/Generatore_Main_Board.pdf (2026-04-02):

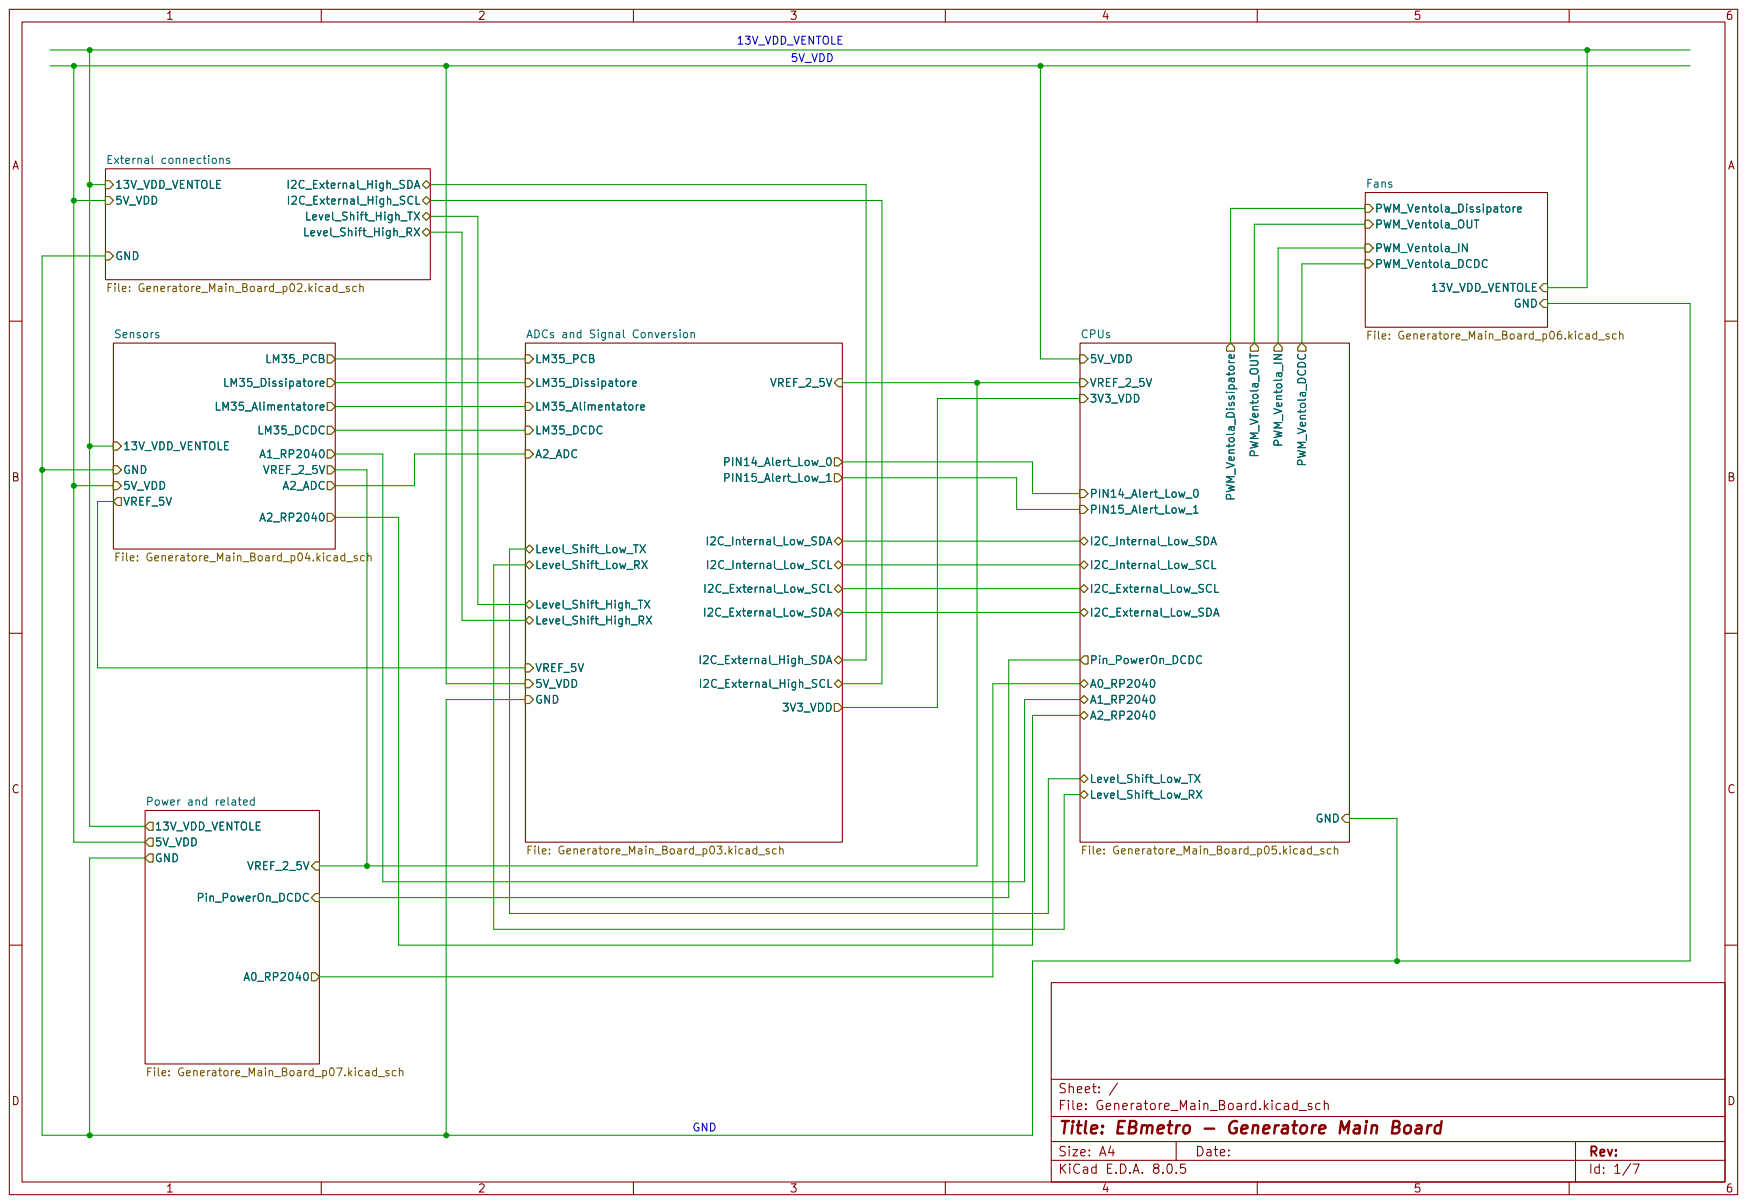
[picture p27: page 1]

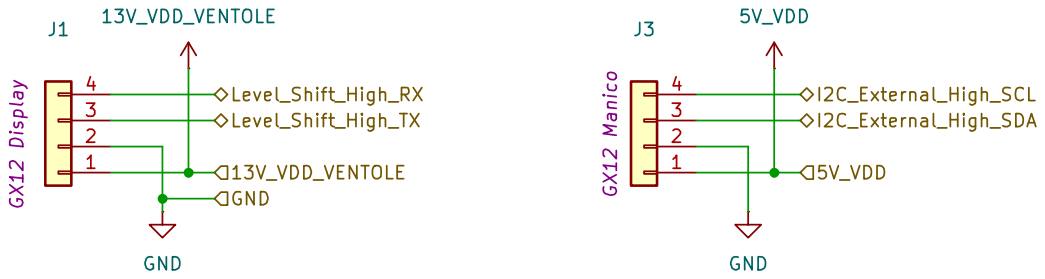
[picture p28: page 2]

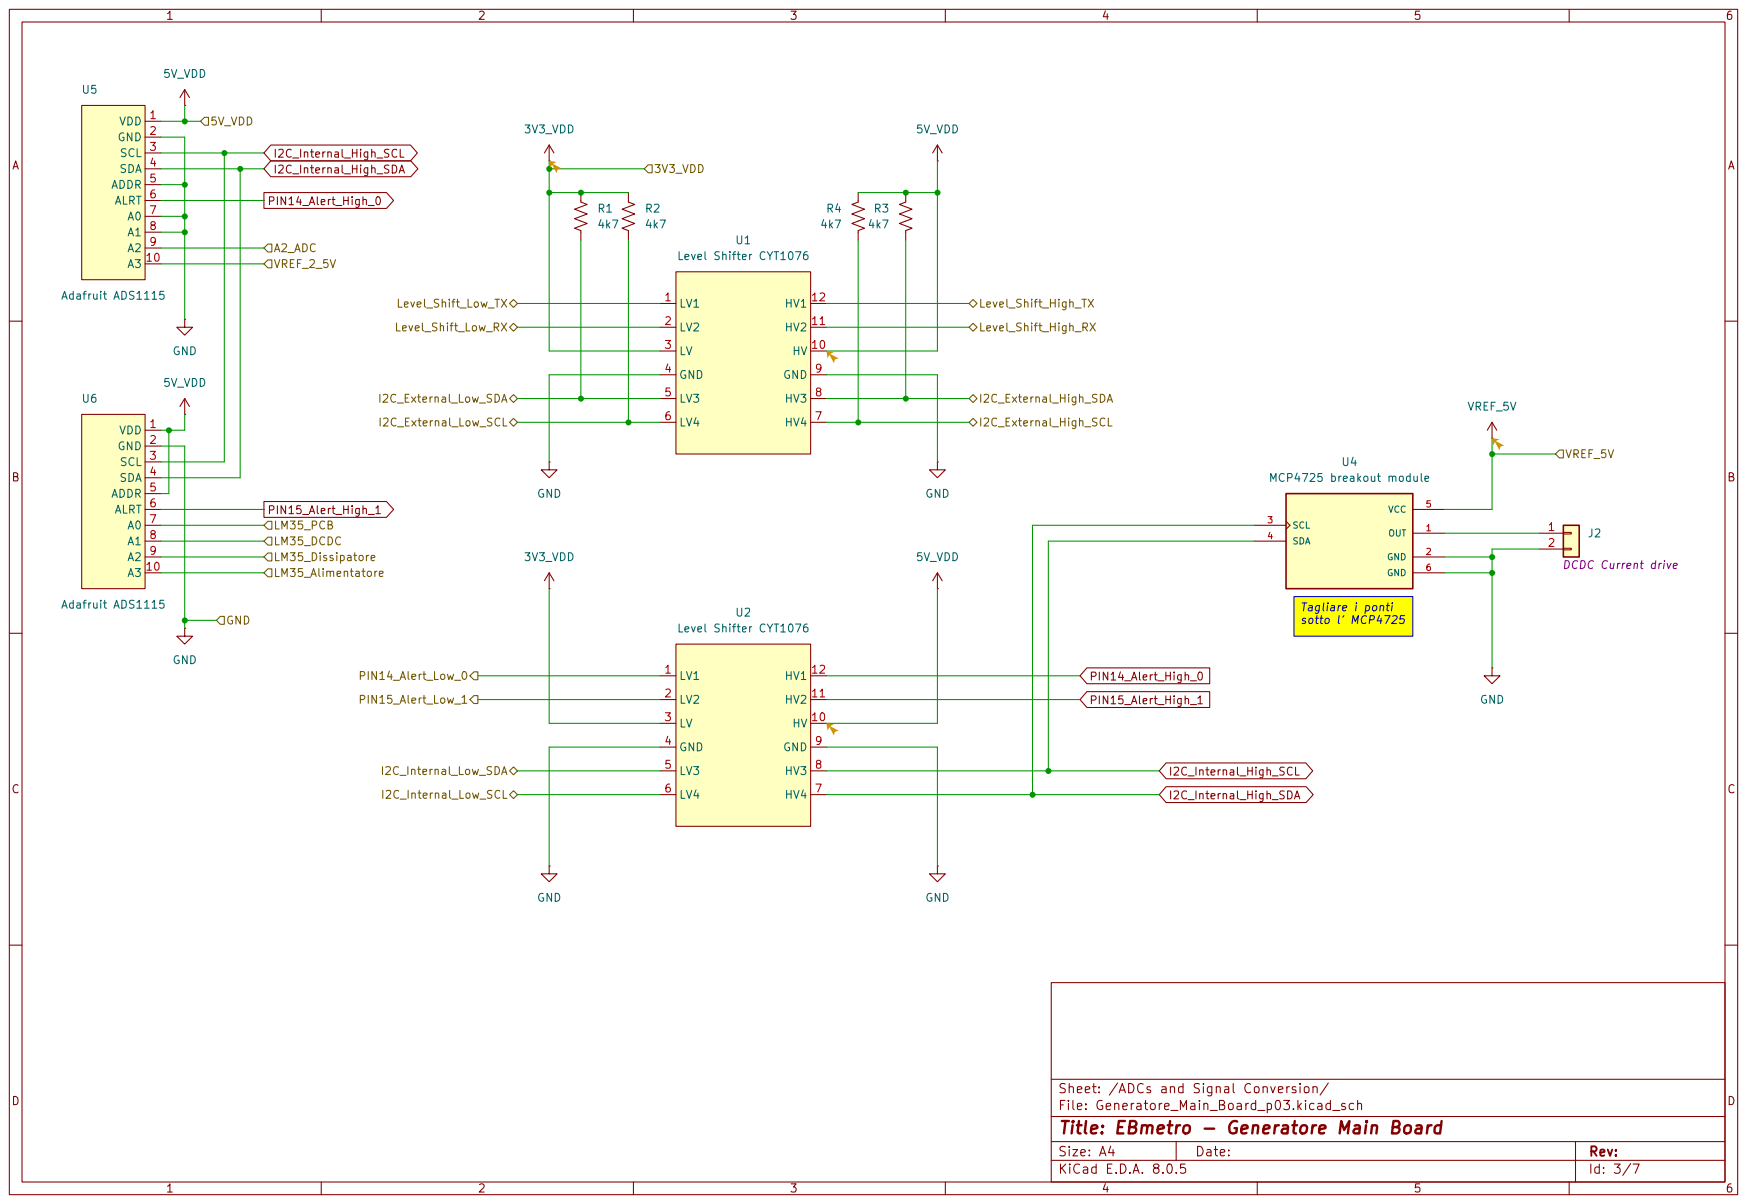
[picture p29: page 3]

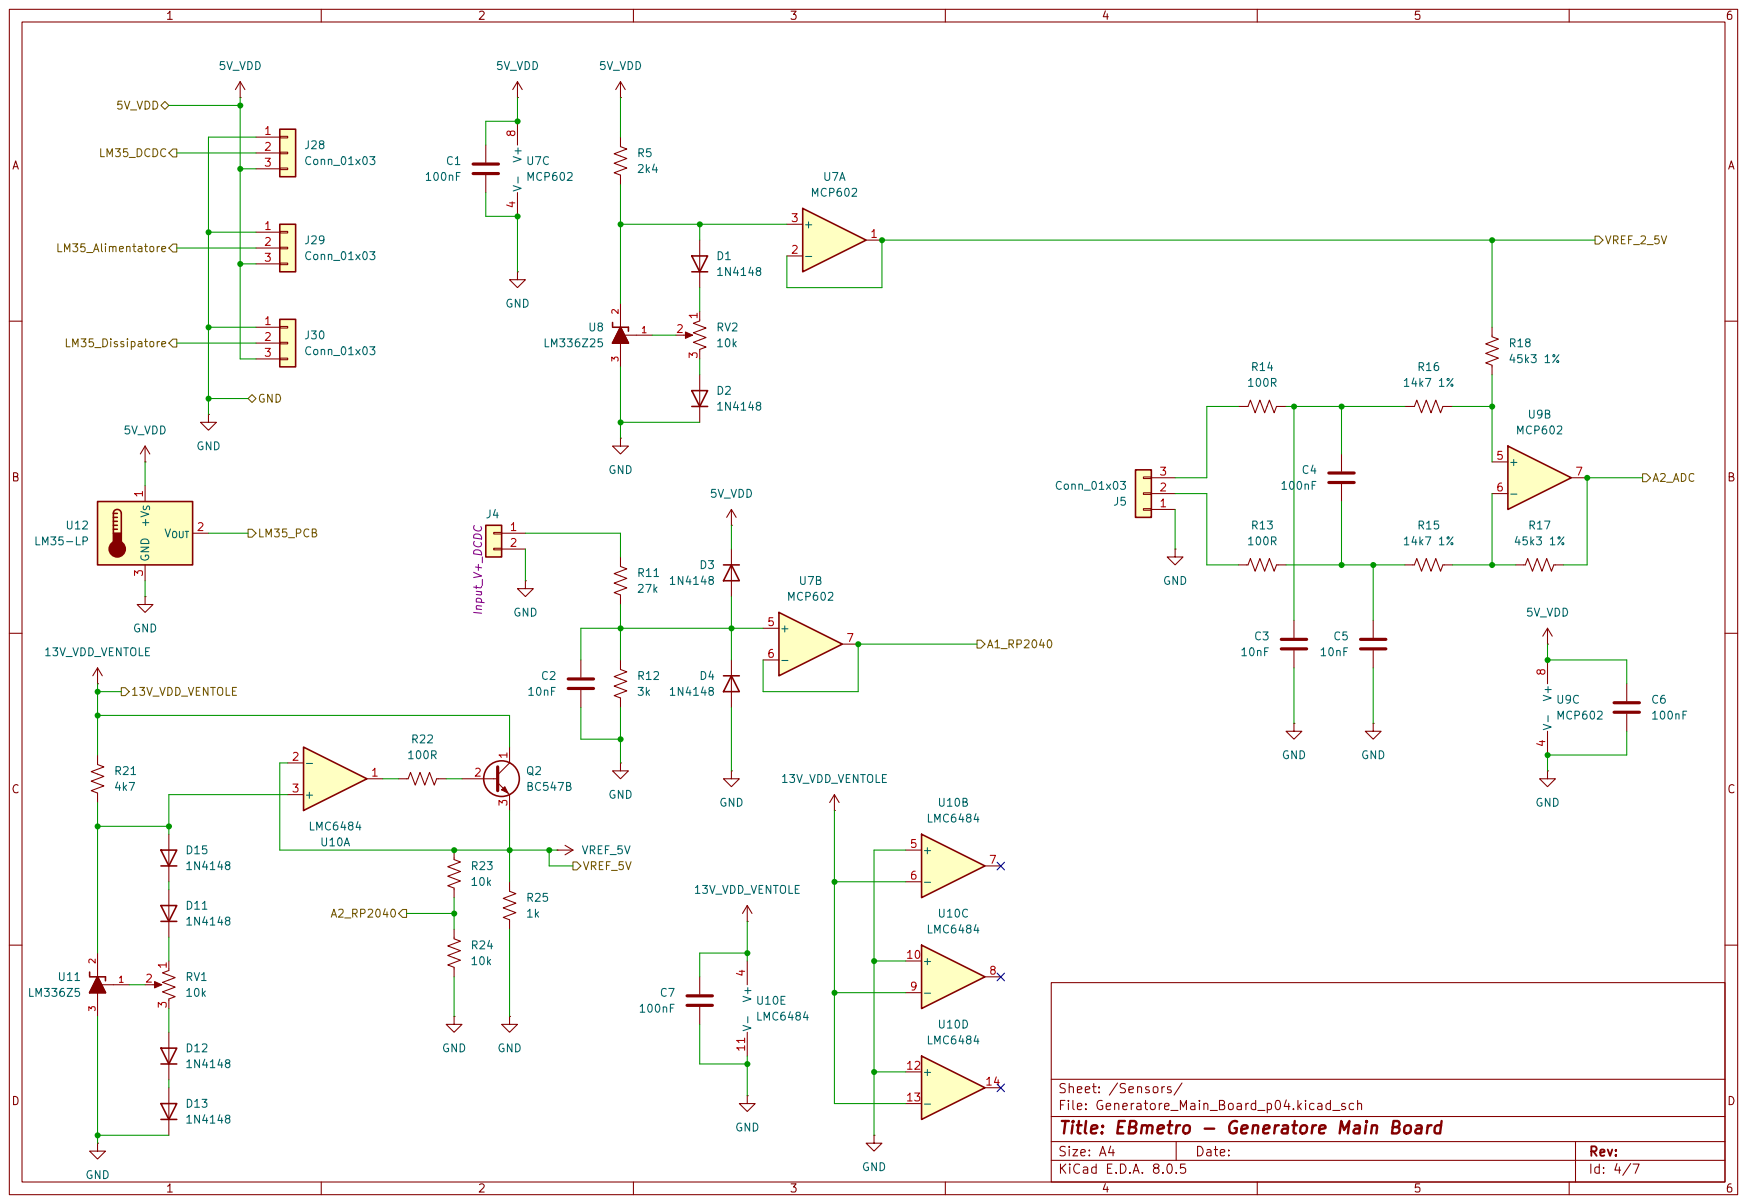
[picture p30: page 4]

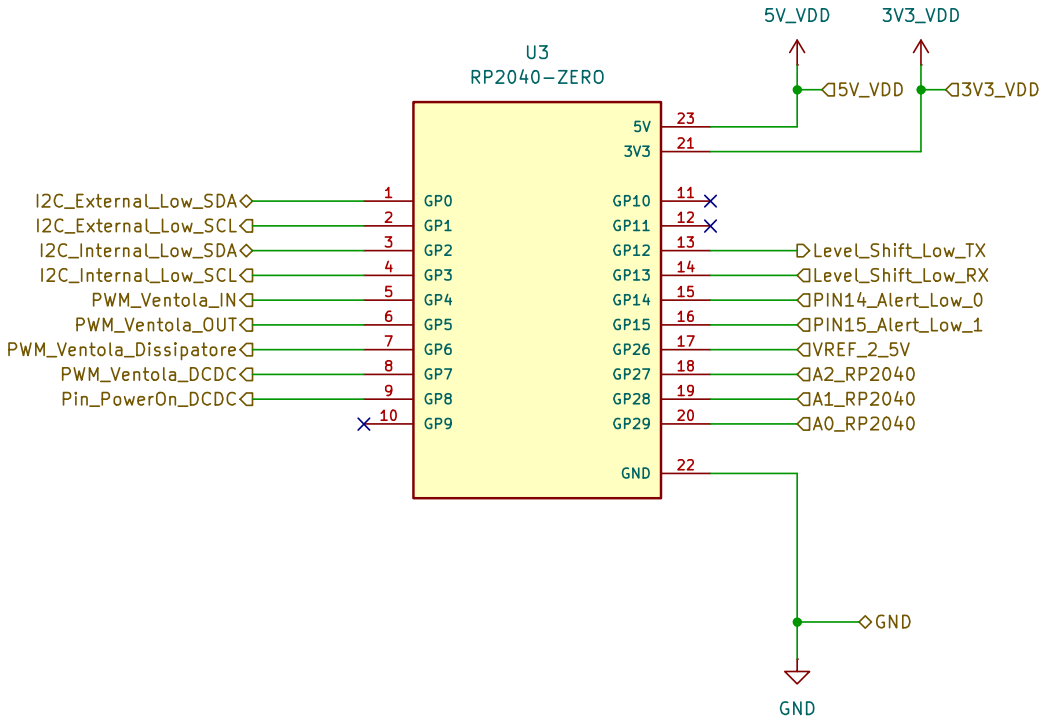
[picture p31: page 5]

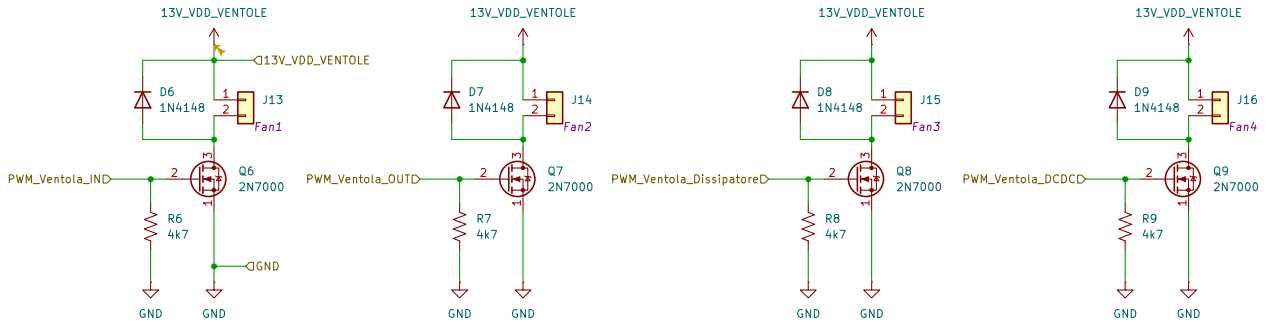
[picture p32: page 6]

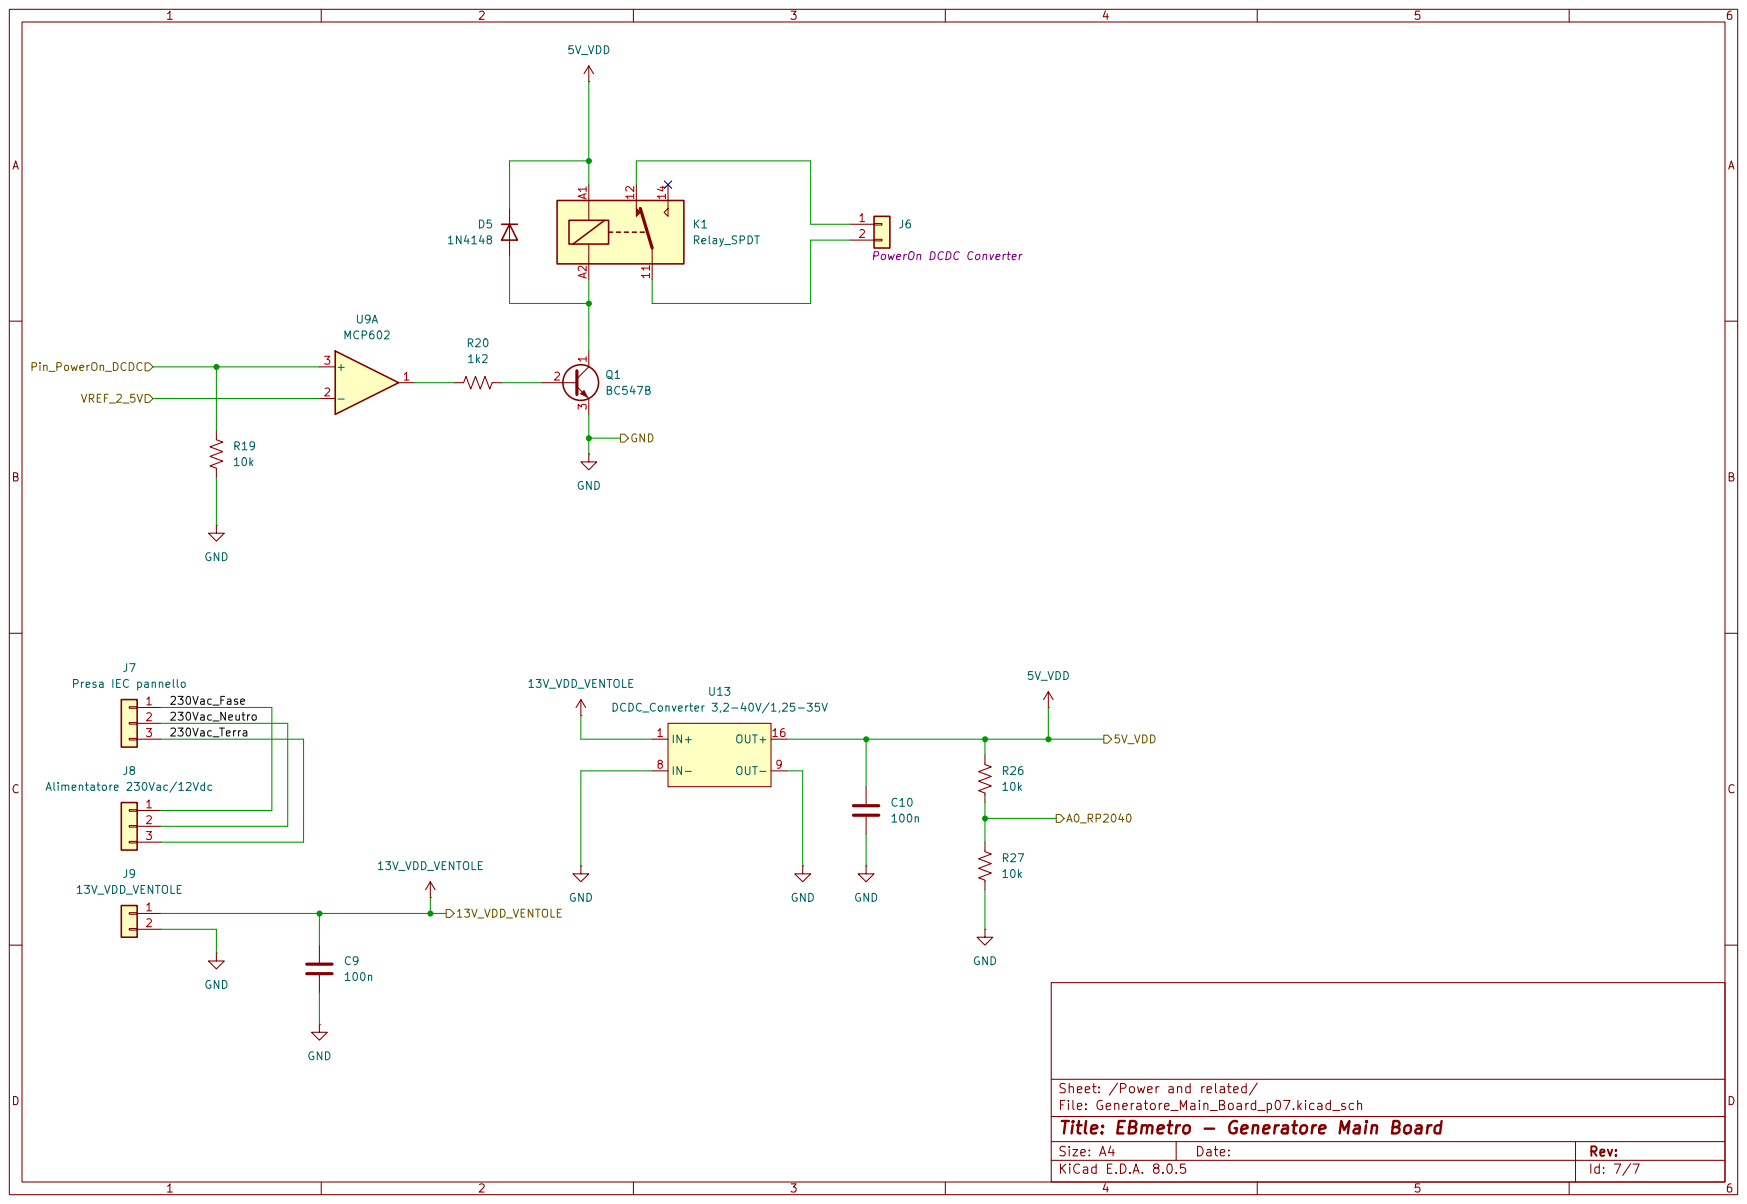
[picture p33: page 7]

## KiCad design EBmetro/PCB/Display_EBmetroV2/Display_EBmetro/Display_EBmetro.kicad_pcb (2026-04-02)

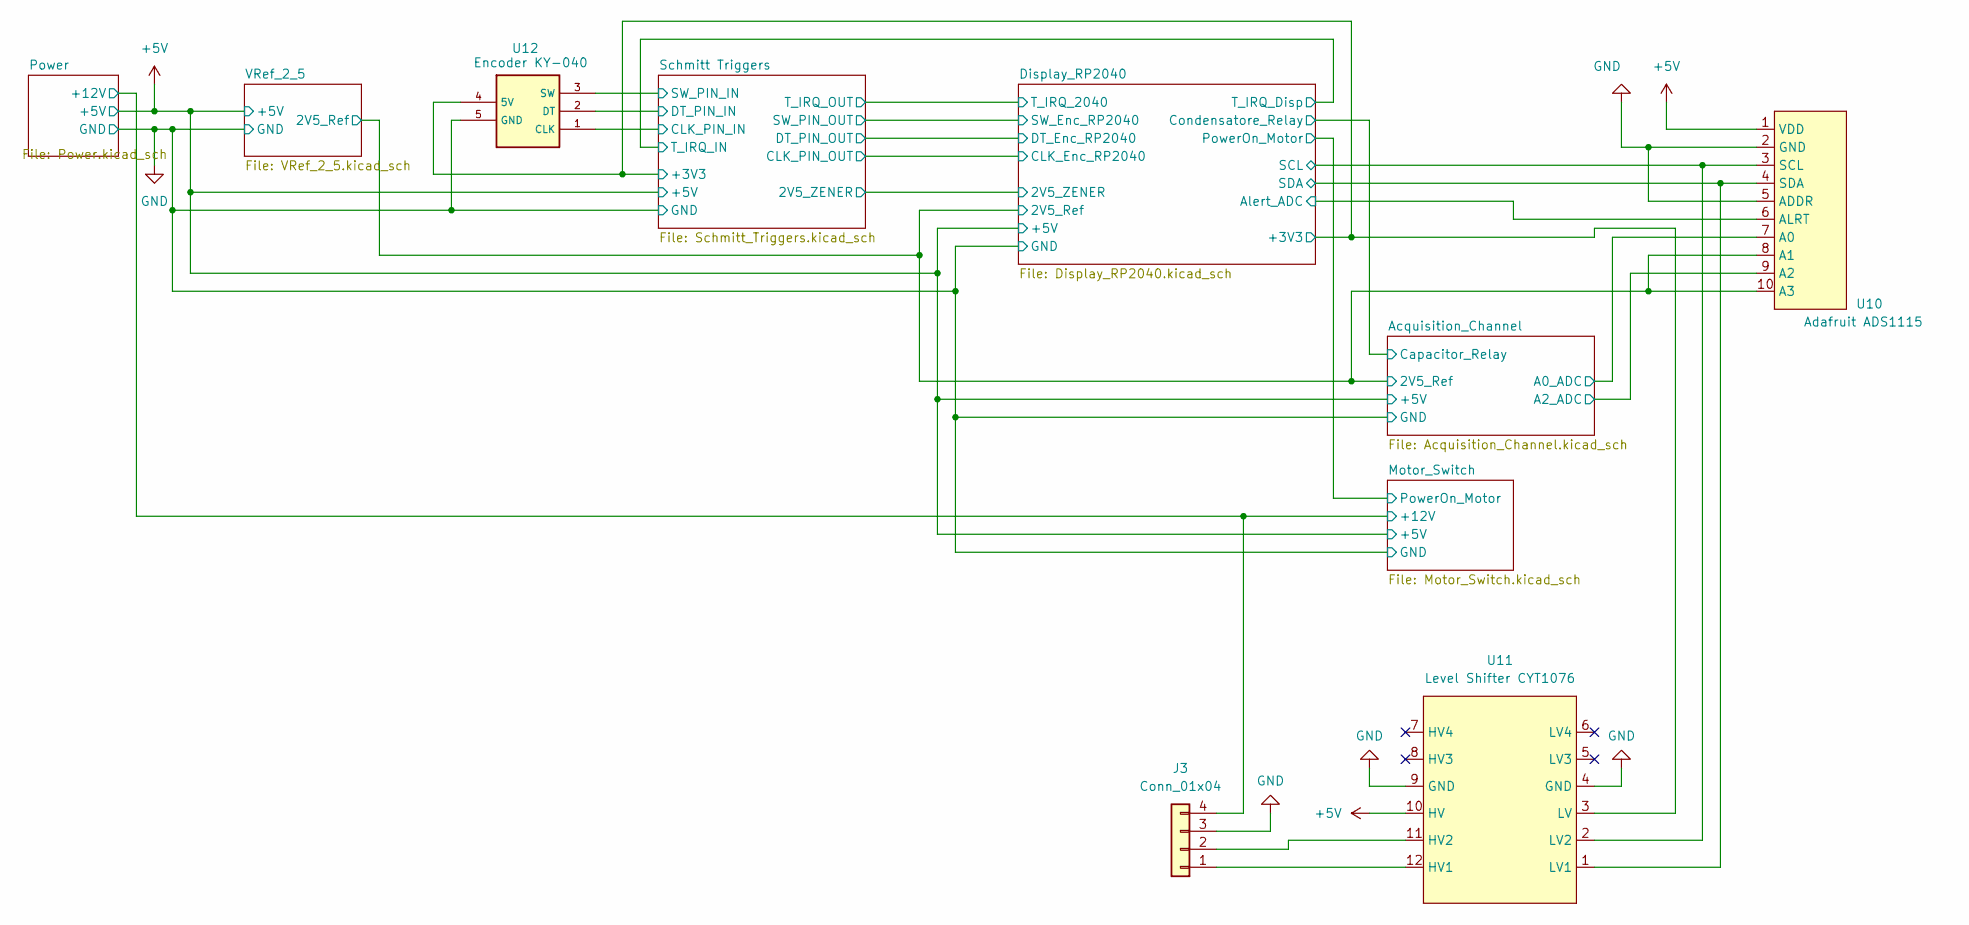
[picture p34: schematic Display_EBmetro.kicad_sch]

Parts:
J3: Conn_01x04; JST_EH_B4B-EH-A_1x04_P2.50mm_Vertical
U10: Adafruit ADS1115; PinSocket_1x10_P2.54mm_Vertical
U11: Level Shifter CYT1076; LevelShifter_CYT1076
U12: Encoder KY-040; Encoder_KY-040

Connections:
+5V: U10.1 (VDD), U11.10 (HV); also elsewhere on the board
+12V: J3.4; also elsewhere on the board
/Acquisition_Channel/2V5_Ref: U10.8 (A1), U10.10 (A3); also elsewhere on the board
/Acquisition_Channel/A0_ADC: U10.7 (A0); also elsewhere on the board
/Acquisition_Channel/A2_ADC: U10.9 (A2); also elsewhere on the board
/Display_RP2040/+3V3: U11.3 (LV), U12.4 (5V); also elsewhere on the board
/Display_RP2040/Alert_ADC: U10.6 (ALRT); also elsewhere on the board
/Display_RP2040/SCL: U10.3 (SCL), U11.2 (LV2); also elsewhere on the board
/Display_RP2040/SDA: U10.4 (SDA), U11.1 (LV1); also elsewhere on the board
/Schmitt Triggers/CLK_PIN_IN: U12.1 (CLK); also elsewhere on the board
/Schmitt Triggers/DT_PIN_IN: U12.2 (DT); also elsewhere on the board
/Schmitt Triggers/SW_PIN_IN: U12.3 (SW); also elsewhere on the board
GND: J3.3, U10.2 (GND), U10.5 (ADDR), U11.4 (GND), U11.9 (GND), U12.5 (GND); also elsewhere on the board
unnamed: J3.1, U11.12 (HV1)
unnamed: J3.2, U11.11 (HV2)

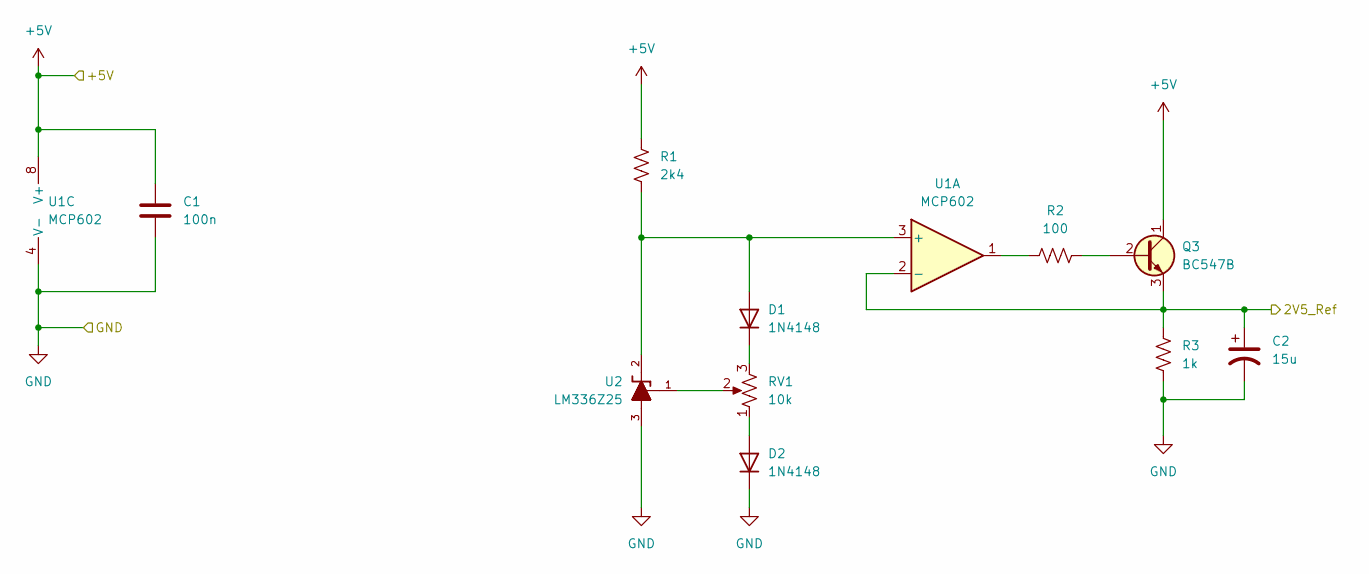
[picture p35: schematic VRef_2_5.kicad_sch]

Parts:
C1: 100n; C_Rect_L7.2mm_W2.5mm_P5.00mm_FKS2_FKP2_MKS2_MKP2
C2: 15u; CP_Radial_Tantal_D5.5mm_P5.00mm
D1, D2: 1N4148; D_DO-35_SOD27_P7.62mm_Horizontal
Q3: BC547B; TO-92_Inline_Wide_CBE
R1: 2k4; R_Axial_DIN0207_L6.3mm_D2.5mm_P10.16mm_Horizontal
R2: 100; R_Axial_DIN0207_L6.3mm_D2.5mm_P10.16mm_Horizontal
R3: 1k; R_Axial_DIN0207_L6.3mm_D2.5mm_P10.16mm_Horizontal
RV1: 10k; Potentiometer_Bourns_3296W_Vertical
U1: MCP602; DIP-8_W7.62mm_Socket
U2: LM336Z25; TO-92L_Inline_Wide

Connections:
+5V: C1.2, Q3.1 (C), R1.1, U1.8 (V+); also elsewhere on the board
/Acquisition_Channel/2V5_Ref: C2.1, Q3.3 (E), R3.1, U1.2 (-); also elsewhere on the board
GND: C1.1, C2.2, D2.1 (K), R3.2, U1.4 (V-), U2.3; also elsewhere on the board
unnamed: D1.2 (A), R1.2, U1.3 (+), U2.2
unnamed: D1.1 (K), RV1.3
unnamed: D2.2 (A), RV1.1
unnamed: Q3.2 (B), R2.2
unnamed: R2.1, U1.1
unnamed: RV1.2, U2.1

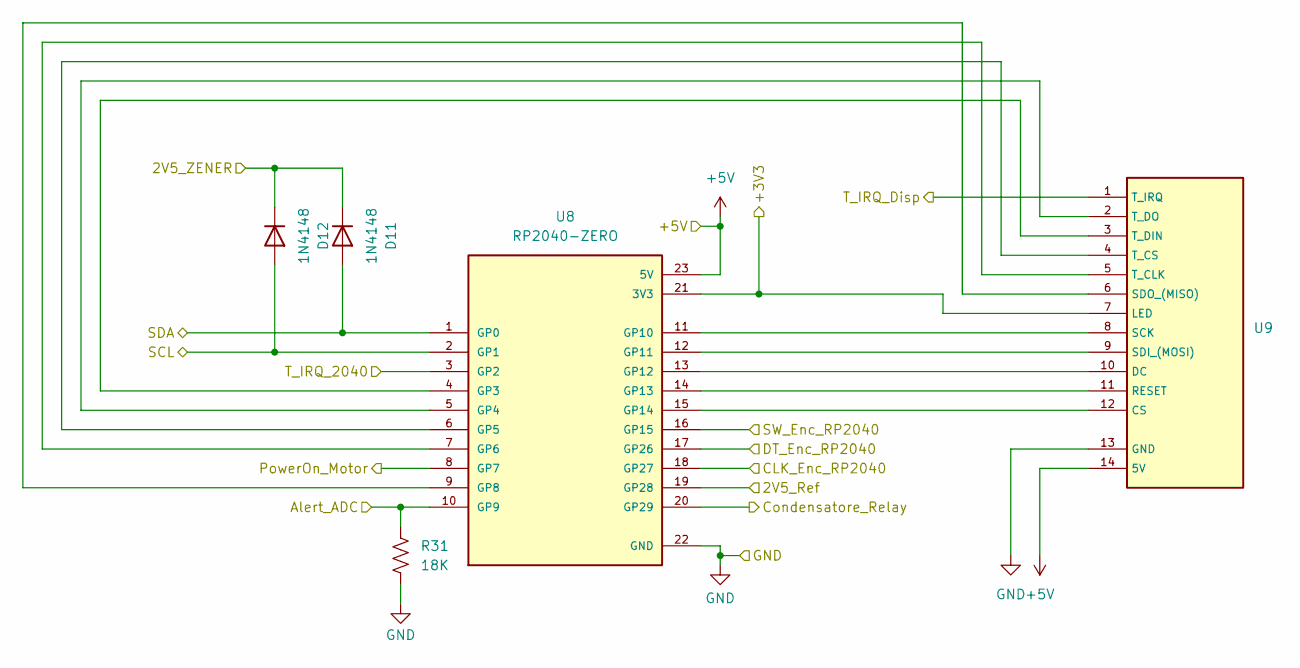
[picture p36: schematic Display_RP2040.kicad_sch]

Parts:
D11, D12: 1N4148; D_DO-35_SOD27_P7.62mm_Horizontal
R31: 18K; R_Axial_DIN0207_L6.3mm_D2.5mm_P10.16mm_Horizontal
U8: RP2040-ZERO; MODULE_RP2040-ZERO_V2; PARTREV NA
U9: Display_TFT_LCD_4

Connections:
+5V: U8.23 (5V), U9.14 (5V); also elsewhere on the board
/Acquisition_Channel/2V5_Ref: U8.19 (GP28); also elsewhere on the board
/Acquisition_Channel/Capacitor_Relay: U8.20 (GP29); also elsewhere on the board
/Display_RP2040/+3V3: U8.21 (3V3), U9.7 (LED); also elsewhere on the board
/Display_RP2040/Alert_ADC: R31.1, U8.10 (GP9); also elsewhere on the board
/Display_RP2040/CLK_Enc_RP2040: U8.18 (GP27); also elsewhere on the board
/Display_RP2040/DT_Enc_RP2040: U8.17 (GP26); also elsewhere on the board
/Display_RP2040/PowerOn_Motor: U8.8 (GP7); also elsewhere on the board
/Display_RP2040/SCL: D12.2 (A), U8.2 (GP1); also elsewhere on the board
/Display_RP2040/SDA: D11.2 (A), U8.1 (GP0); also elsewhere on the board
/Display_RP2040/SW_Enc_RP2040: U8.16 (GP15); also elsewhere on the board
/Display_RP2040/T_IRQ_2040: U8.3 (GP2); also elsewhere on the board
/Display_RP2040/T_IRQ_Disp: U9.1 (T_IRQ); also elsewhere on the board
/Schmitt Triggers/2V5_ZENER: D11.1 (K), D12.1 (K); also elsewhere on the board
GND: R31.2, U8.22 (GND), U9.13 (GND); also elsewhere on the board
unnamed: U8.4 (GP3), U9.3 (T_DIN)
unnamed: U8.5 (GP4), U9.2 (T_DO)
unnamed: U8.6 (GP5), U9.4 (T_CS)
unnamed: U8.7 (GP6), U9.5 (T_CLK)
unnamed: U8.9 (GP8), U9.6 (SDO_(MISO))
unnamed: U8.11 (GP10), U9.8 (SCK)
unnamed: U8.12 (GP11), U9.9 (SDI_(MOSI))
unnamed: U8.13 (GP12), U9.10 (DC)
unnamed: U8.14 (GP13), U9.11 (RESET)
unnamed: U8.15 (GP14), U9.12 (CS)

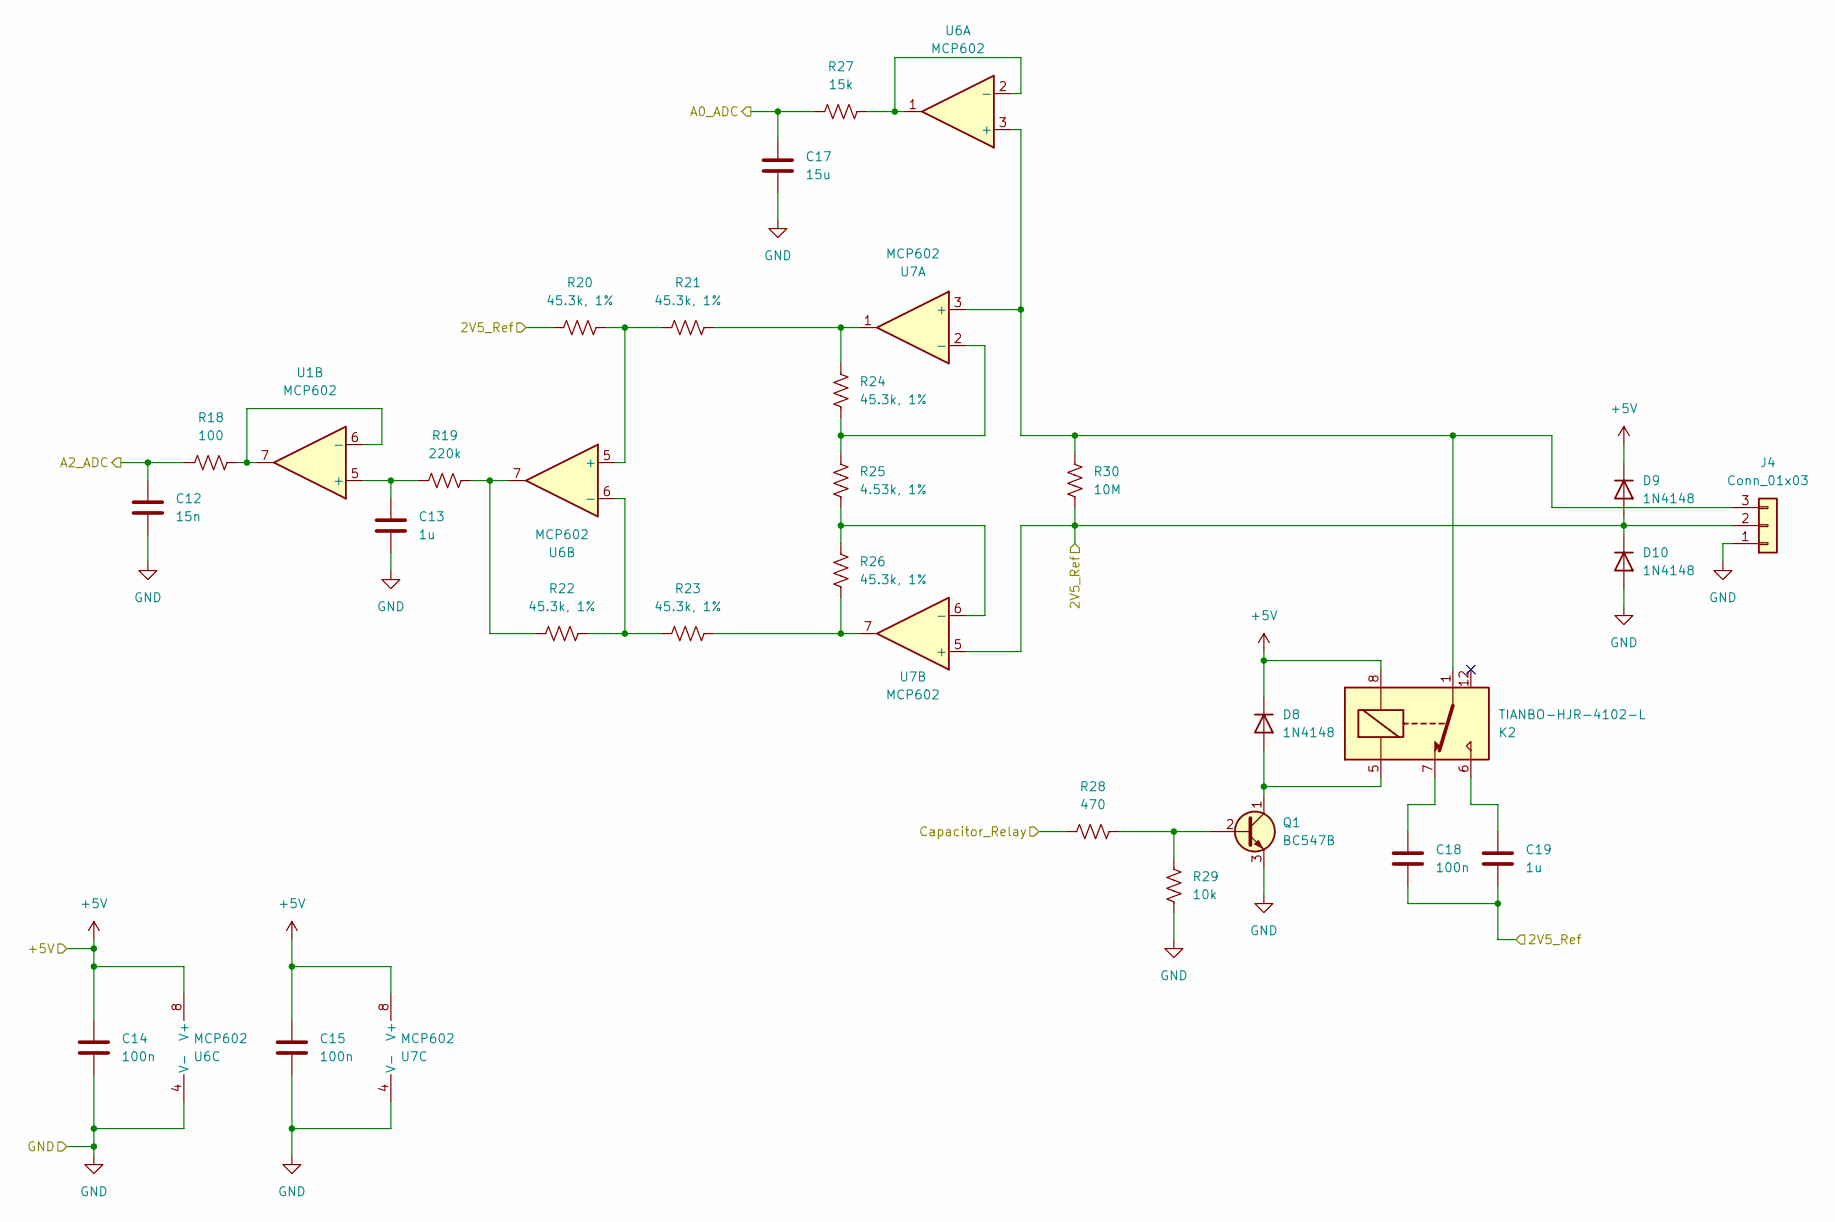
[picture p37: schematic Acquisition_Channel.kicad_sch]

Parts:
C12: 15n; C_Rect_L7.2mm_W2.5mm_P5.00mm_FKS2_FKP2_MKS2_MKP2
C13, C19: 1u; C_Rect_L7.2mm_W5.5mm_P5.00mm_FKS2_FKP2_MKS2_MKP2
C14, C15, C18: 100n; C_Rect_L7.2mm_W2.5mm_P5.00mm_FKS2_FKP2_MKS2_MKP2
C17: 15u; C_Rect_L7.2mm_W2.5mm_P5.00mm_FKS2_FKP2_MKS2_MKP2
D8, D9, D10: 1N4148; D_DO-35_SOD27_P7.62mm_Horizontal
J4: Conn_01x03; JST_EH_B3B-EH-A_1x03_P2.50mm_Vertical
K2: TIANBO-HJR-4102-L; Relay_SPDT_HJR-4102
Q1: BC547B; TO-92_Inline_Wide_CBE
R18: 100; R_Axial_DIN0207_L6.3mm_D2.5mm_P10.16mm_Horizontal
R19: 220k; R_Axial_DIN0207_L6.3mm_D2.5mm_P10.16mm_Horizontal
R20, R21, R22, R23, R24, R26: 45.3k, 1%; R_Axial_DIN0207_L6.3mm_D2.5mm_P10.16mm_Horizontal
R25: 4.53k, 1%; R_Axial_DIN0207_L6.3mm_D2.5mm_P10.16mm_Horizontal
R27: 15k; R_Axial_DIN0207_L6.3mm_D2.5mm_P10.16mm_Horizontal
R28: 470; R_Axial_DIN0207_L6.3mm_D2.5mm_P10.16mm_Horizontal
R29: 10k; R_Axial_DIN0207_L6.3mm_D2.5mm_P10.16mm_Horizontal
R30: 10M; R_Axial_DIN0207_L6.3mm_D2.5mm_P10.16mm_Horizontal
U1, U6, U7: MCP602; DIP-8_W7.62mm_Socket

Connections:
+5V: C14.1, C15.1, D8.1 (K), D9.1 (K), K2.8, U6.8 (V+), U7.8 (V+); also elsewhere on the board
/Acquisition_Channel/2V5_Ref: C18.2, C19.2, D9.2 (A), D10.1 (K), J4.2, R20.1, R30.2, U7.5 (+); also elsewhere on the board
/Acquisition_Channel/A0_ADC: C17.1, R27.2; also elsewhere on the board
/Acquisition_Channel/A2_ADC: C12.1, R18.1; also elsewhere on the board
/Acquisition_Channel/Capacitor_Relay: R28.2; also elsewhere on the board
GND: C12.2, C13.2, C14.2, C15.2, C17.2, D10.2 (A), J4.1, Q1.3 (E), R29.2, U6.4 (V-), U7.4 (V-); also elsewhere on the board
unnamed: C18.1, K2.7
unnamed: C19.1, K2.6
unnamed: D8.2 (A), K2.5, Q1.1 (C)
unnamed: J4.3, K2.1, R30.1, U6.3 (+), U7.3 (+)
unnamed: Q1.2 (B), R28.1, R29.1
unnamed: R19.2, R22.1, U6.7
unnamed: R21.2, R24.2, U7.1
unnamed: R23.2, R26.1, U7.7
unnamed: C13.1, R19.1, U1.5 (+)
unnamed: R18.2, U1.6 (-), U1.7
unnamed: R27.1, U6.1, U6.2 (-)
unnamed: R20.2, R21.1, U6.5 (+)
unnamed: R22.2, R23.1, U6.6 (-)
unnamed: R24.1, R25.2, U7.2 (-)
unnamed: R25.1, R26.2, U7.6 (-)

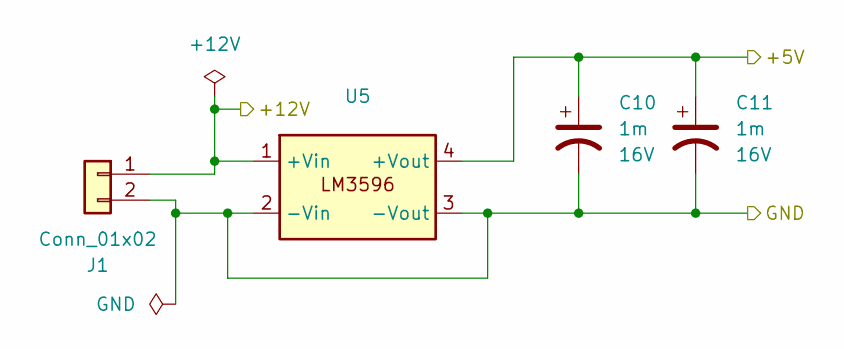
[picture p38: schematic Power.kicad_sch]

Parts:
C10, C11: 1m; CP_Radial_D10.0mm_P5.00mm; Voltage 16V
J1: Conn_01x02; JST_EH_B2B-EH-A_1x02_P2.50mm_Vertical
U5: LM3596

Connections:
+5V: C10.1, C11.1, U5.4 (+Vout); also elsewhere on the board
+12V: J1.1, U5.1 (+Vin); also elsewhere on the board
GND: C10.2, C11.2, J1.2, U5.2 (-Vin), U5.3 (-Vout); also elsewhere on the board

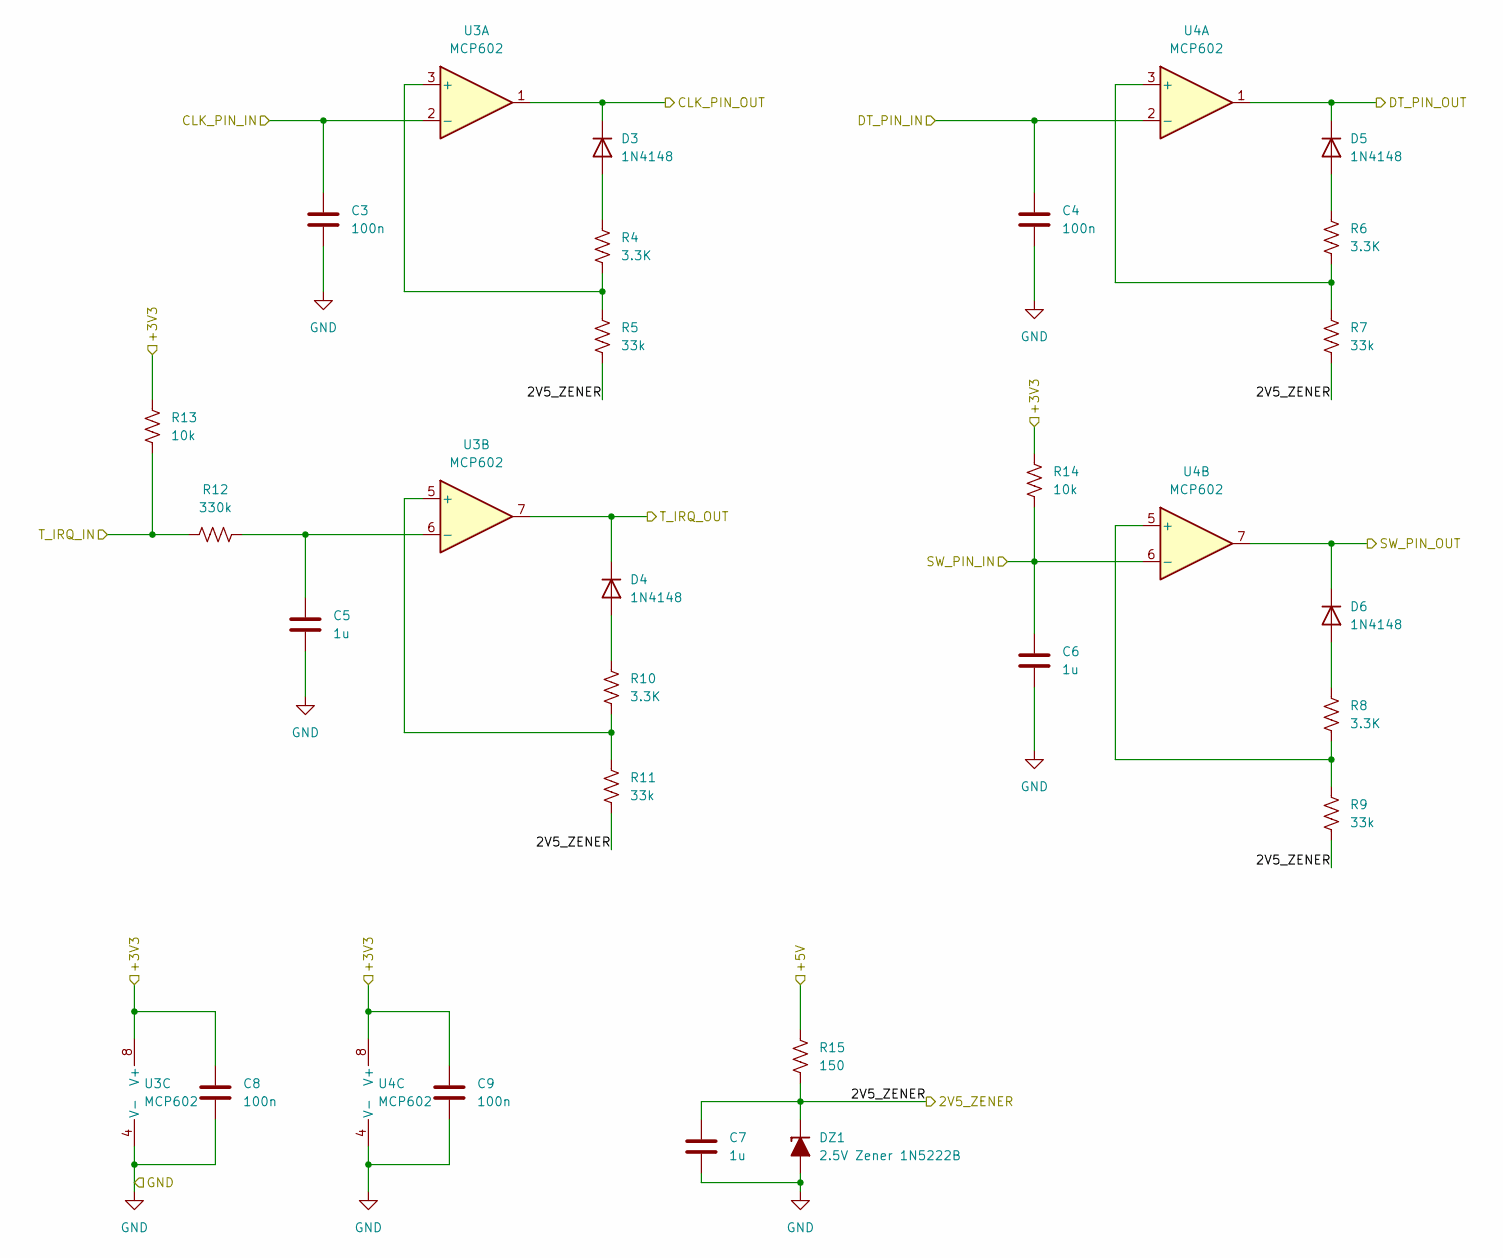
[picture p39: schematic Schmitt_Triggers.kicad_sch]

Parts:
C3, C4, C8, C9: 100n; C_Rect_L7.2mm_W2.5mm_P5.00mm_FKS2_FKP2_MKS2_MKP2
C5, C6, C7: 1u; C_Rect_L7.2mm_W5.5mm_P5.00mm_FKS2_FKP2_MKS2_MKP2
D3, D4, D5, D6: 1N4148; D_DO-35_SOD27_P7.62mm_Horizontal
DZ1: 2.5V Zener 1N5222B; D_DO-35_SOD27_P10.16mm_Horizontal_Zener
R4, R6, R8, R10: 3.3K; R_Axial_DIN0207_L6.3mm_D2.5mm_P10.16mm_Horizontal
R5, R7, R9, R11: 33k; R_Axial_DIN0207_L6.3mm_D2.5mm_P10.16mm_Horizontal
R12: 330k; R_Axial_DIN0207_L6.3mm_D2.5mm_P10.16mm_Horizontal
R13, R14: 10k; R_Axial_DIN0207_L6.3mm_D2.5mm_P10.16mm_Horizontal
R15: 150; R_Axial_DIN0207_L6.3mm_D2.5mm_P10.16mm_Horizontal
U3, U4: MCP602; DIP-8_W7.62mm_Socket

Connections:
+5V: R15.1; also elsewhere on the board
/Display_RP2040/+3V3: C8.1, C9.1, R13.2, R14.1, U3.8 (V+), U4.8 (V+); also elsewhere on the board
/Display_RP2040/CLK_Enc_RP2040: D3.1 (K), U3.1; also elsewhere on the board
/Display_RP2040/DT_Enc_RP2040: D5.1 (K), U4.1; also elsewhere on the board
/Display_RP2040/SW_Enc_RP2040: D6.1 (K), U4.7; also elsewhere on the board
/Display_RP2040/T_IRQ_2040: D4.1 (K), U3.7; also elsewhere on the board
/Display_RP2040/T_IRQ_Disp: R12.2, R13.1; also elsewhere on the board
/Schmitt Triggers/2V5_ZENER: C7.1, DZ1.1 (K), R5.2, R7.2, R9.2, R11.2, R15.2; also elsewhere on the board
/Schmitt Triggers/CLK_PIN_IN: C3.1, U3.2 (-); also elsewhere on the board
/Schmitt Triggers/DT_PIN_IN: C4.1, U4.2 (-); also elsewhere on the board
/Schmitt Triggers/SW_PIN_IN: C6.1, R14.2, U4.6 (-); also elsewhere on the board
GND: C3.2, C4.2, C5.2, C6.2, C7.2, C8.2, C9.2, DZ1.2 (A), U3.4 (V-), U4.4 (V-); also elsewhere on the board
unnamed: D3.2 (A), R4.1
unnamed: D4.2 (A), R10.1
unnamed: D5.2 (A), R6.1
unnamed: D6.2 (A), R8.1
unnamed: R4.2, R5.1, U3.3 (+)
unnamed: R10.2, R11.1, U3.5 (+)
unnamed: C5.1, R12.1, U3.6 (-)
unnamed: R6.2, R7.1, U4.3 (+)
unnamed: R8.2, R9.1, U4.5 (+)

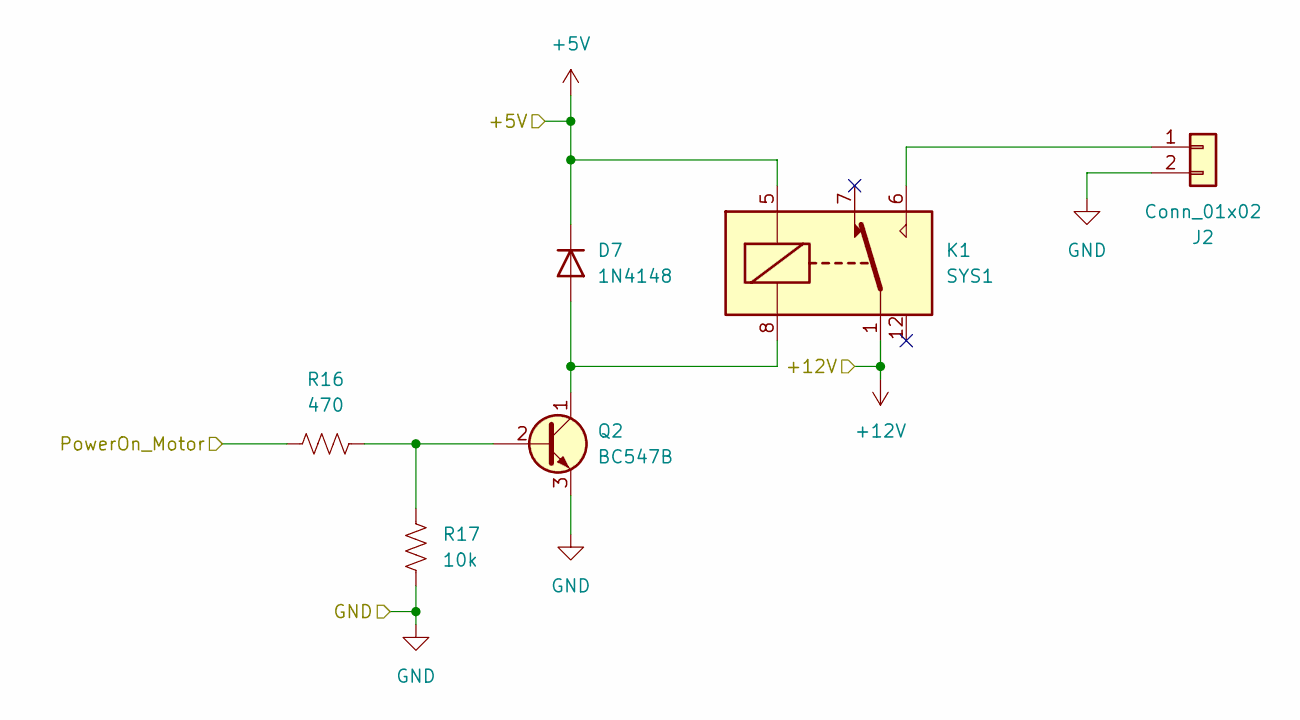
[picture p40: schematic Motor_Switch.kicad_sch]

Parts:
D7: 1N4148; D_DO-35_SOD27_P7.62mm_Horizontal
J2: Conn_01x02; JST_EH_B2B-EH-A_1x02_P2.50mm_Vertical
K1: SYS1; Relay_SPDT_HJR-4102
Q2: BC547B; TO-92_Inline_Wide_CBE
R16: 470; R_Axial_DIN0207_L6.3mm_D2.5mm_P10.16mm_Horizontal
R17: 10k; R_Axial_DIN0207_L6.3mm_D2.5mm_P10.16mm_Horizontal

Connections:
+5V: D7.1 (K), K1.5; also elsewhere on the board
+12V: K1.1; also elsewhere on the board
/Display_RP2040/PowerOn_Motor: R16.1; also elsewhere on the board
GND: J2.2, Q2.3 (E), R17.1; also elsewhere on the board
unnamed: D7.2 (A), K1.8, Q2.1 (C)
unnamed: J2.1, K1.6
unnamed: Q2.2 (B), R16.2, R17.2

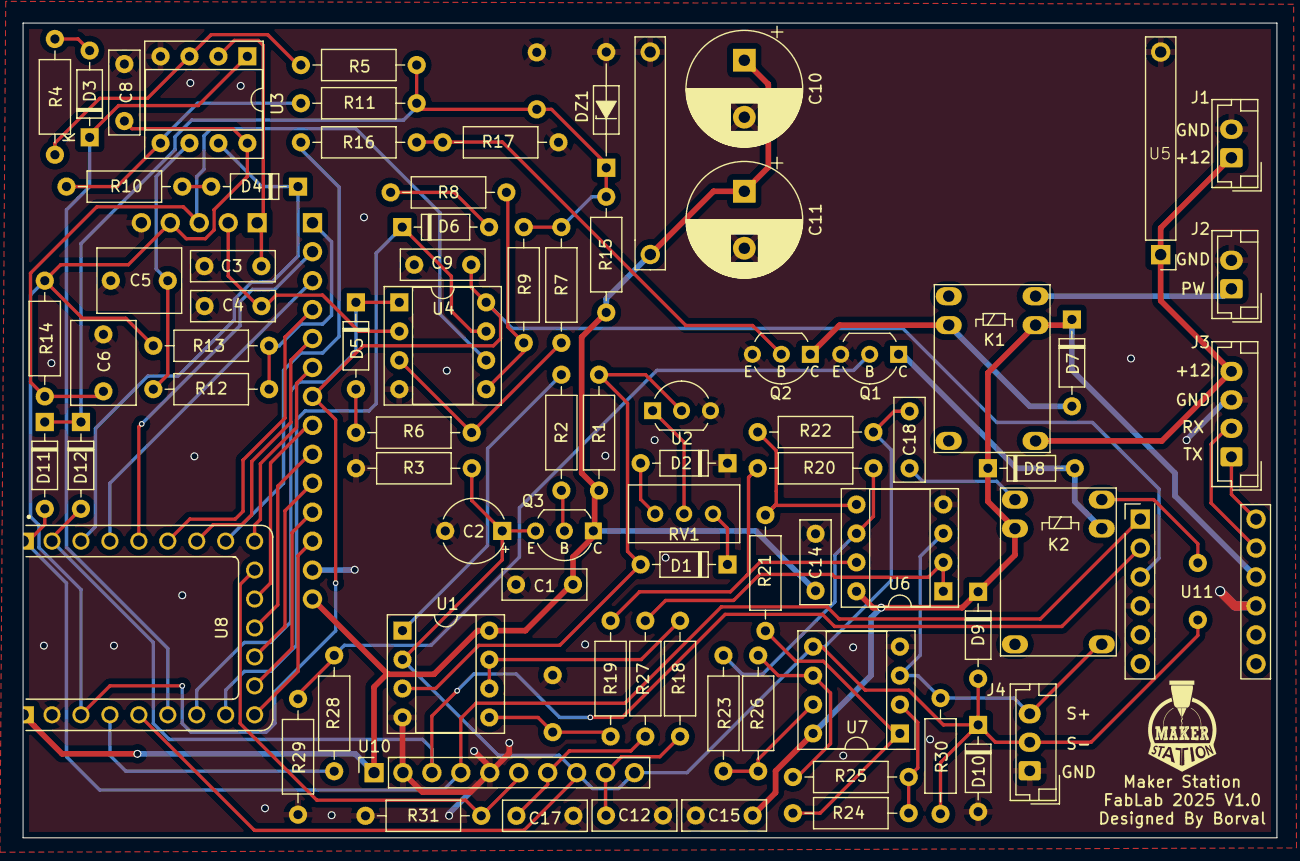
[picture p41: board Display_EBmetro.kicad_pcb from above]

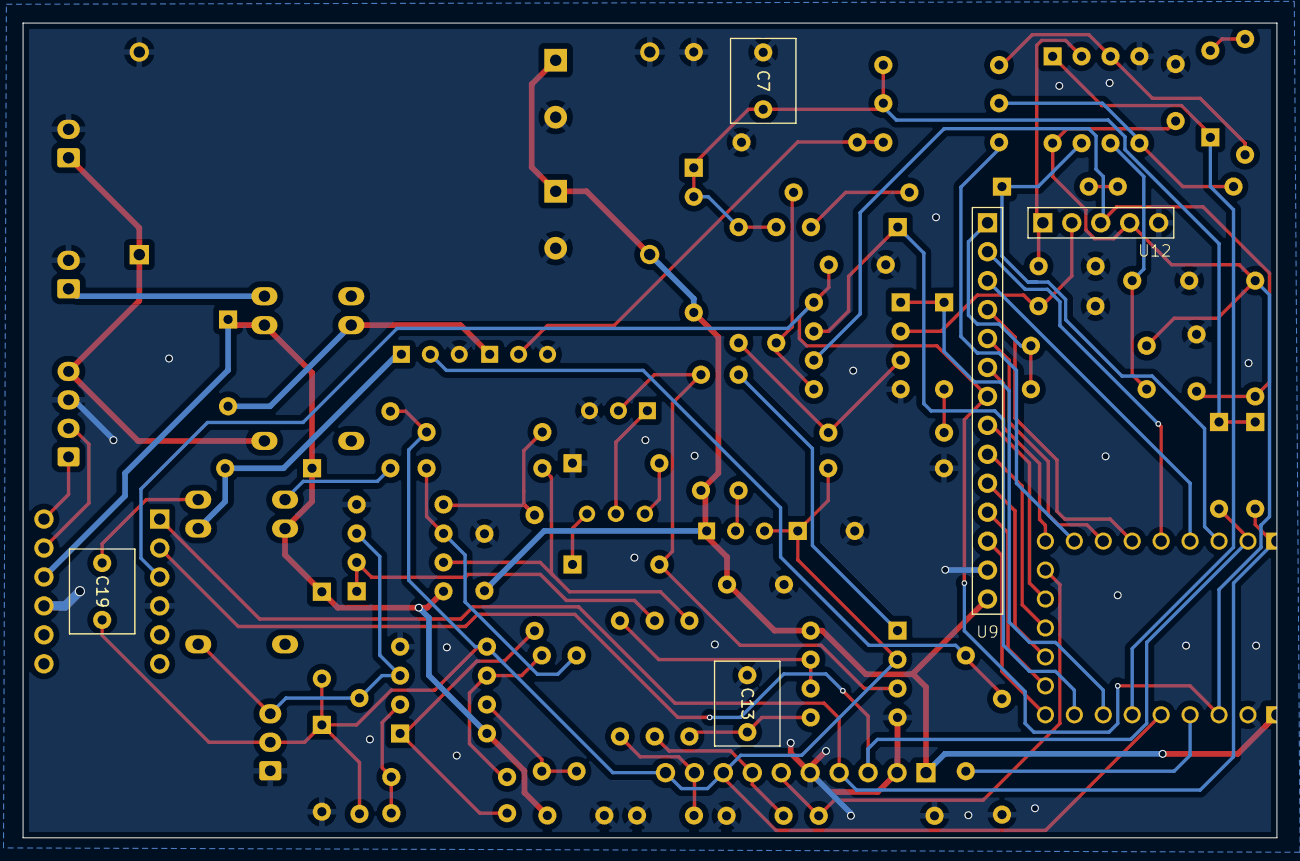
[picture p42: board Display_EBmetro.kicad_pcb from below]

Board: 2 copper layers, 110.0 x 71.5 mm, 84 parts (5 on the bottom side), 66 nets.

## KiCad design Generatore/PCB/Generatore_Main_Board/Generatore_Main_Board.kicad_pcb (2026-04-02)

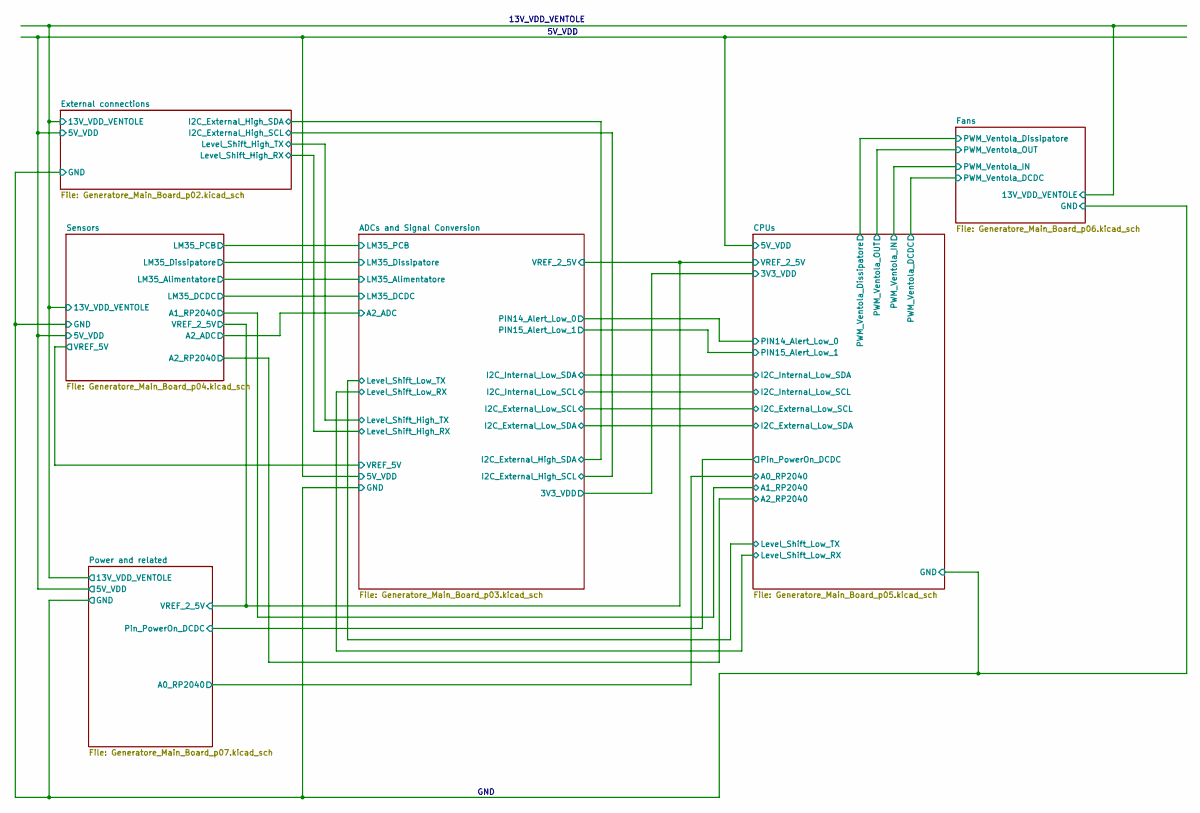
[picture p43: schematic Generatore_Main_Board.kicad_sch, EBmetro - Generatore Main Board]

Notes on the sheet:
13V_VDD_VENTOLE
GND
5V_VDD

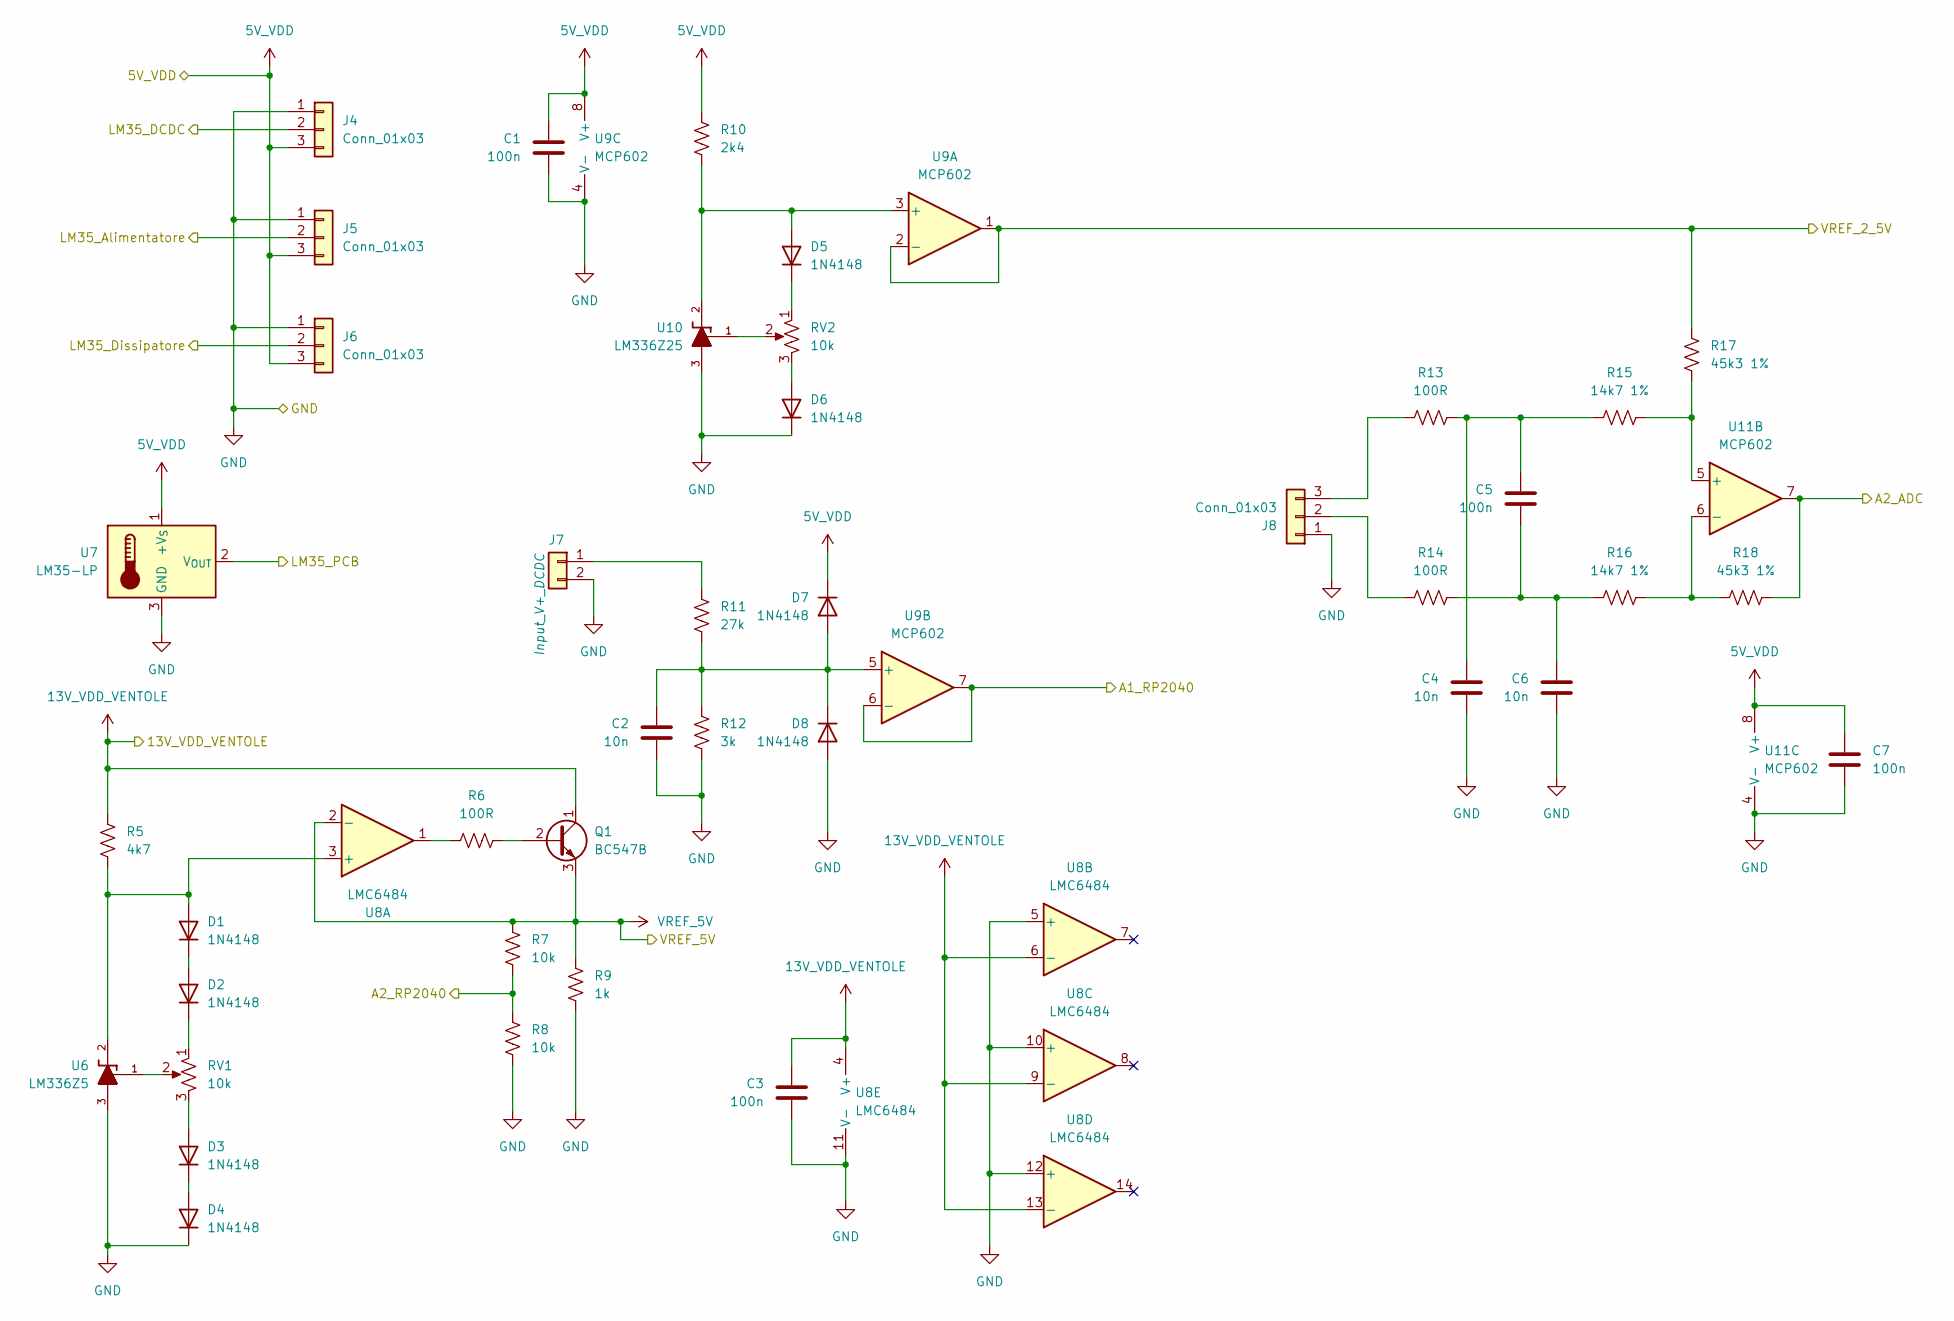
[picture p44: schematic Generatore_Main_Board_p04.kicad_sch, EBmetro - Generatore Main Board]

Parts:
C1, C3, C5, C7: 100n; Term_Block_1x2_P5mm
C2, C4, C6: 10n; Term_Block_1x2_P5mm
D1, D2, D3, D4, D5, D6, D7, D8: 1N4148; D_DO-35_SOD27_P7.62mm_Horizontal
J4, J5, J6, J8: Conn_01x03; JST_EH_B3B-EH-A_1x03_P2.50mm_Vertical
J7: Conn_01x02; JST_EH_B2B-EH-A_1x02_P2.50mm_Vertical
Q1: BC547B; TO-92_Inline
R5: 4k7; R_Axial_DIN0207_L6.3mm_D2.5mm_P10.16mm_Horizontal
R6, R13, R14: 100R; R_Axial_DIN0207_L6.3mm_D2.5mm_P10.16mm_Horizontal
R7, R8: 10k; R_Axial_DIN0207_L6.3mm_D2.5mm_P10.16mm_Horizontal
R9: 1k; R_Axial_DIN0207_L6.3mm_D2.5mm_P10.16mm_Horizontal
R10: 2k4; R_Axial_DIN0207_L6.3mm_D2.5mm_P10.16mm_Horizontal
R11: 27k; R_Axial_DIN0207_L6.3mm_D2.5mm_P10.16mm_Horizontal
R12: 3k; R_Axial_DIN0207_L6.3mm_D2.5mm_P10.16mm_Horizontal
R15, R16: 14k7 1%; R_Axial_DIN0207_L6.3mm_D2.5mm_P10.16mm_Horizontal
R17, R18: 45k3 1%; R_Axial_DIN0207_L6.3mm_D2.5mm_P10.16mm_Horizontal
RV1, RV2: 10k; Potentiometer_Bourns_3296W_Vertical
U6: LM336Z5; TO-92-TO92-254P520H877-3
U7: LM35-LP; TO-92_Inline
U8: LMC6484; CERDIP-14_W7.62mm_SideBrazed_LongPads_Socket
U9, U11: MCP602; CERDIP-8_W7.62mm_SideBrazed_LongPads_Socket
U10: LM336Z25; TO-92-TO92-254P520H877-3

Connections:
5V_VDD: C1.1, C7.1, D7.1 (K), J4.3, J5.3, J6.3, R10.1, U7.1 (+V_{S}), U9.8 (V+), U11.8 (V+); also elsewhere on the board
13V_VDD_VENTOLE: C3.1, Q1.1 (C), R5.1, U8.4 (V+), U8.6 (-), U8.9 (-), U8.13 (-); also elsewhere on the board
/ADCs and Signal Conversion/A2_ADC: R18.1, U11.7; also elsewhere on the board
/ADCs and Signal Conversion/LM35_Alimentatore: J5.2; also elsewhere on the board
/ADCs and Signal Conversion/LM35_DCDC: J4.2; also elsewhere on the board
/ADCs and Signal Conversion/LM35_Dissipatore: J6.2; also elsewhere on the board
/ADCs and Signal Conversion/LM35_PCB: U7.2 (V_{OUT}); also elsewhere on the board
/ADCs and Signal Conversion/VREF_2_5V: R17.1, U9.1, U9.2 (-); also elsewhere on the board
/CPUs/A1_RP2040: U9.6 (-), U9.7; also elsewhere on the board
/CPUs/A2_RP2040: R7.2, R8.1; also elsewhere on the board
GND: C1.2, C2.2, C3.2, C4.2, C6.2, C7.2, D4.1 (K), D6.1 (K), D8.2 (A), J4.1, J5.1, J6.1, J7.2, J8.1, R8.2, R9.2, R12.2, U6.3, U7.3 (GND), U8.5 (+), U8.10 (+), U8.11 (V-), U8.12 (+), U9.4 (V-), U10.3, U11.4 (V-); also elsewhere on the board
unnamed: C4.1, C5.1, R13.2, R15.1
unnamed: C5.2, C6.1, R14.2, R16.1
unnamed: D1.2 (A), R5.2, U6.2, U8.3 (+)
unnamed: D1.1 (K), D2.2 (A)
unnamed: D2.1 (K), RV1.1
unnamed: D3.2 (A), RV1.3
unnamed: D3.1 (K), D4.2 (A)
unnamed: D5.2 (A), R10.2, U9.3 (+), U10.2
unnamed: D5.1 (K), RV2.1
unnamed: D6.2 (A), RV2.3
unnamed: C2.1, D7.2 (A), D8.1 (K), R11.2, R12.1, U9.5 (+)
unnamed: J7.1, R11.1
unnamed: J8.2, R14.1
unnamed: J8.3, R13.1
unnamed: Q1.2 (B), R6.2
unnamed: R6.1, U8.1
unnamed: RV1.2, U6.1
unnamed: RV2.2, U10.1
unnamed: R15.2, R17.2, U11.5 (+)
unnamed: R16.2, R18.2, U11.6 (-)
VREF_5V: Q1.3 (E), R7.1, R9.1, U8.2 (-); also elsewhere on the board

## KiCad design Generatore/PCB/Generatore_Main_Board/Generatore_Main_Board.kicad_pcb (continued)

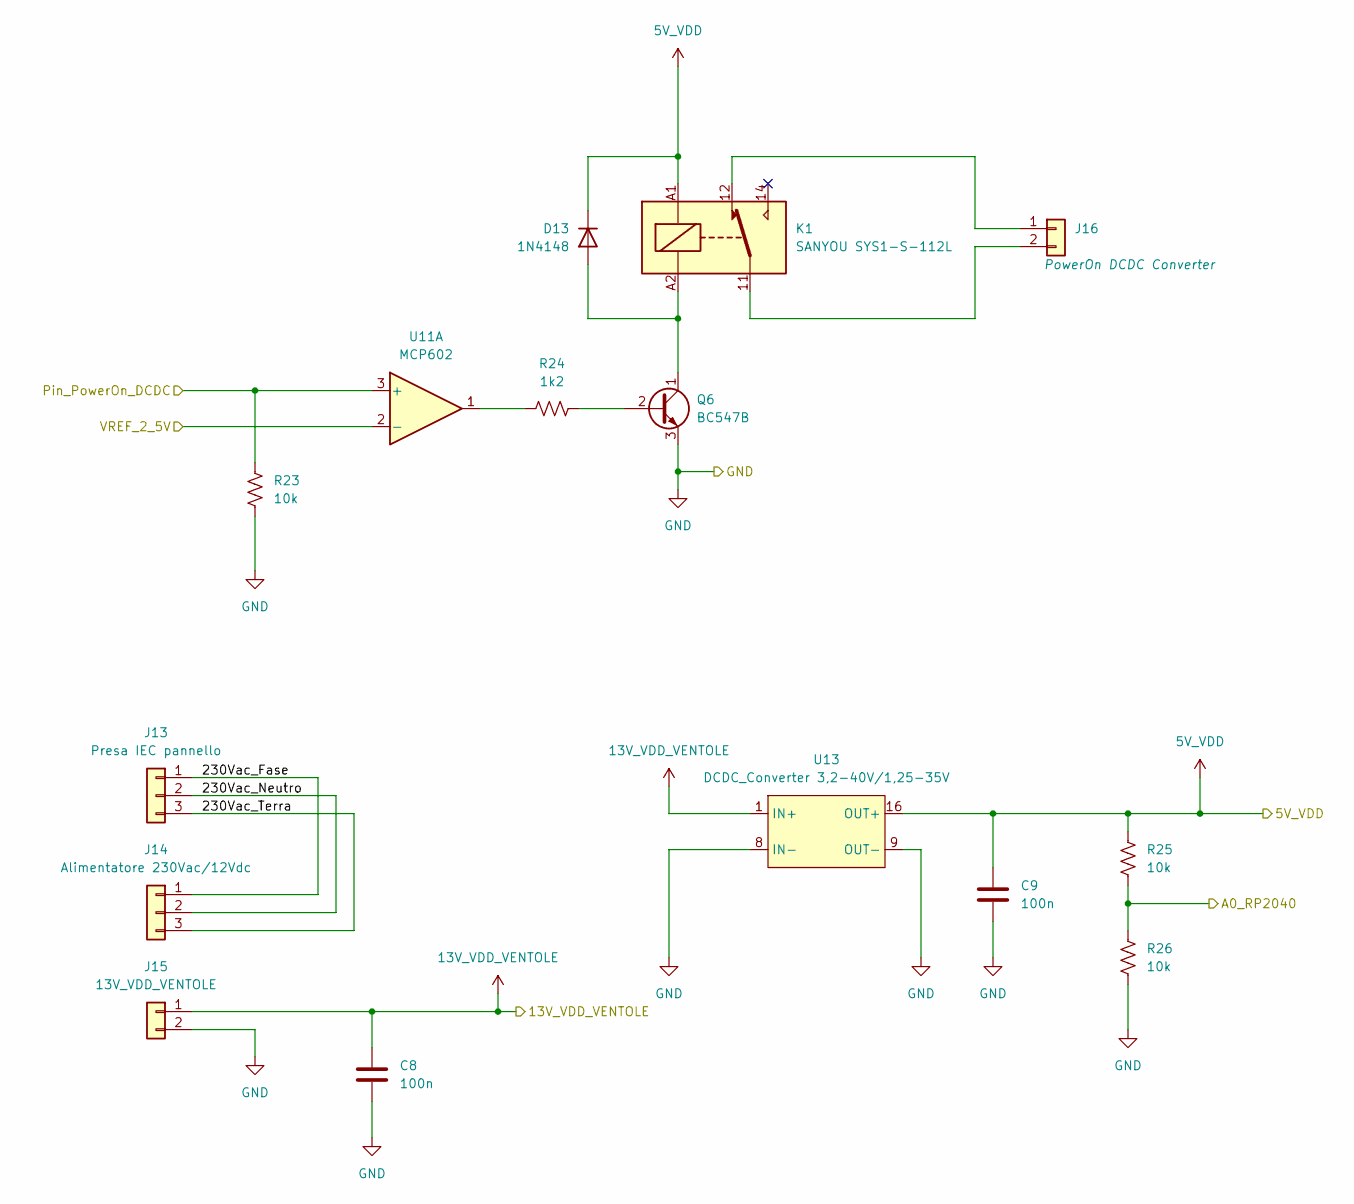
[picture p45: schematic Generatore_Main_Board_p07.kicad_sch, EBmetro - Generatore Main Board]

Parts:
C8, C9: 100n; Term_Block_1x2_P5mm
D13: 1N4148; D_DO-35_SOD27_P7.62mm_Horizontal
J13: Presa IEC pannello; TerminalBlock_Phoenix_MKDS-3-3-5.08_1x03_P5.08mm_Horizontal
J14: Alimentatore 230Vac/12Vdc; TerminalBlock_Phoenix_MKDS-3-3-5.08_1x03_P5.08mm_Horizontal
J15: 13V_VDD_VENTOLE; TerminalBlock_Phoenix_MKDS-3-2-5.08_1x02_P5.08mm_Horizontal
J16: Conn_01x02; JST_EH_B2B-EH-A_1x02_P2.50mm_Vertical
K1: SANYOU SYS1-S-112L; Relay_SPDT_Sanyou_SYS1-S-112L
Q6: BC547B; TO-92_Inline
R23, R25, R26: 10k; R_Axial_DIN0207_L6.3mm_D2.5mm_P10.16mm_Horizontal
R24: 1k2; R_Axial_DIN0207_L6.3mm_D2.5mm_P10.16mm_Horizontal
U11: MCP602; CERDIP-8_W7.62mm_SideBrazed_LongPads_Socket
U13: DCDC_Converter 3,2-40V/1,25-35V; DCDC_Converter 3,2-40V_1,25-35V

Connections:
5V_VDD: C9.1, D13.1 (K), K1.A1, R25.1, U13.16 (OUT+); also elsewhere on the board
13V_VDD_VENTOLE: C8.1, J15.1, U13.1 (IN+); also elsewhere on the board
/ADCs and Signal Conversion/VREF_2_5V: U11.2 (-); also elsewhere on the board
/CPUs/A0_RP2040: R25.2, R26.1; also elsewhere on the board
/CPUs/Pin_PowerOn_DCDC: R23.1, U11.3 (+); also elsewhere on the board
/Power and related/230Vac_Fase: J13.1, J14.1
/Power and related/230Vac_Neutro: J13.2, J14.2
/Power and related/230Vac_Terra: J13.3, J14.3
GND: C8.2, C9.2, J15.2, Q6.3 (E), R23.2, R26.2, U13.8 (IN-), U13.9 (OUT-); also elsewhere on the board
unnamed: D13.2 (A), K1.A2, Q6.1 (C)
unnamed: J16.1, K1.12
unnamed: J16.2, K1.11
unnamed: Q6.2 (B), R24.2
unnamed: R24.1, U11.1


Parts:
D9, D10, D11, D12: 1N4148; D_DO-35_SOD27_P7.62mm_Horizontal
J9, J10, J11, J12: Conn_01x02; JST_XH_B2B-XH-A_1x02_P2.50mm_Vertical
Q2, Q3, Q4, Q5: 2N7000; TO-92_Inline
R19, R20, R21, R22: 4k7; R_Axial_DIN0207_L6.3mm_D2.5mm_P10.16mm_Horizontal

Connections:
13V_VDD_VENTOLE: D9.1 (K), D10.1 (K), D11.1 (K), D12.1 (K), J9.1, J10.1, J11.1, J12.1; also elsewhere on the board
/CPUs/PWM_Ventola_DCDC: Q5.2 (G), R22.1; also elsewhere on the board
/CPUs/PWM_Ventola_Dissipatore: Q4.2 (G), R21.1; also elsewhere on the board
/CPUs/PWM_Ventola_IN: Q2.2 (G), R19.1; also elsewhere on the board
/CPUs/PWM_Ventola_OUT: Q3.2 (G), R20.1; also elsewhere on the board
GND: Q2.1 (S), Q3.1 (S), Q4.1 (S), Q5.1 (S), R19.2, R20.2, R21.2, R22.2; also elsewhere on the board
unnamed: D9.2 (A), J9.2, Q2.3 (D)
unnamed: D10.2 (A), J10.2, Q3.3 (D)
unnamed: D11.2 (A), J11.2, Q4.3 (D)
unnamed: D12.2 (A), J12.2, Q5.3 (D)


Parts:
U12: RP2040-ZERO; MODULE_RP2040-ZERO; PARTREV NA

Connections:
3V3_VDD: U12.21 (3V3); also elsewhere on the board
5V_VDD: U12.23 (5V); also elsewhere on the board
/ADCs and Signal Conversion/I2C_External_Low_SCL: U12.2 (GP1); also elsewhere on the board
/ADCs and Signal Conversion/I2C_External_Low_SDA: U12.1 (GP0); also elsewhere on the board
/ADCs and Signal Conversion/I2C_Internal_Low_SCL: U12.4 (GP3); also elsewhere on the board
/ADCs and Signal Conversion/I2C_Internal_Low_SDA: U12.3 (GP2); also elsewhere on the board
/ADCs and Signal Conversion/Level_Shift_Low_RX: U12.14 (GP13); also elsewhere on the board
/ADCs and Signal Conversion/Level_Shift_Low_TX: U12.13 (GP12); also elsewhere on the board
/ADCs and Signal Conversion/PIN14_Alert_Low_0: U12.15 (GP14); also elsewhere on the board
/ADCs and Signal Conversion/PIN15_Alert_Low_1: U12.16 (GP15); also elsewhere on the board
/ADCs and Signal Conversion/VREF_2_5V: U12.17 (GP26); also elsewhere on the board
/CPUs/A0_RP2040: U12.20 (GP29); also elsewhere on the board
/CPUs/A1_RP2040: U12.19 (GP28); also elsewhere on the board
/CPUs/A2_RP2040: U12.18 (GP27); also elsewhere on the board
/CPUs/PWM_Ventola_DCDC: U12.8 (GP7); also elsewhere on the board
/CPUs/PWM_Ventola_Dissipatore: U12.7 (GP6); also elsewhere on the board
/CPUs/PWM_Ventola_IN: U12.5 (GP4); also elsewhere on the board
/CPUs/PWM_Ventola_OUT: U12.6 (GP5); also elsewhere on the board
/CPUs/Pin_PowerOn_DCDC: U12.9 (GP8); also elsewhere on the board
GND: U12.22 (GND); also elsewhere on the board


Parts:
J1, J2: Conn_01x04; JST_XH_B4B-XH-A_1x04_P2.50mm_Vertical

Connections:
5V_VDD: J2.1; also elsewhere on the board
13V_VDD_VENTOLE: J1.1; also elsewhere on the board
/ADCs and Signal Conversion/I2C_External_High_SCL: J2.4; also elsewhere on the board
/ADCs and Signal Conversion/I2C_External_High_SDA: J2.3; also elsewhere on the board
/ADCs and Signal Conversion/Level_Shift_High_RX: J1.4; also elsewhere on the board
/ADCs and Signal Conversion/Level_Shift_High_TX: J1.3; also elsewhere on the board
GND: J1.2, J2.2; also elsewhere on the board


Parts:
J3: Conn_01x02; JST_EH_B2B-EH-A_1x02_P2.50mm_Vertical
R1, R2, R3, R4: 4k7; R_Axial_DIN0207_L6.3mm_D2.5mm_P10.16mm_Horizontal
U1, U2: Adafruit ADS1115; PinSocket_1x10_P2.54mm_Vertical
U3, U4: Level Shifter CYT1076; LevelShifter_CYT1076
U5: MCP4725 breakout module; MODULE_ZC576300; PARTREV v14

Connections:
3V3_VDD: R1.1, R2.1, U3.3 (LV), U4.3 (LV); also elsewhere on the board
5V_VDD: R3.1, R4.1, U1.1 (VDD), U2.1 (VDD), U2.5 (ADDR), U3.10 (HV), U4.10 (HV); also elsewhere on the board
/ADCs and Signal Conversion/A2_ADC: U1.9 (A2); also elsewhere on the board
/ADCs and Signal Conversion/I2C_External_High_SCL: R3.2, U3.7 (HV4); also elsewhere on the board
/ADCs and Signal Conversion/I2C_External_High_SDA: R4.2, U3.8 (HV3); also elsewhere on the board
/ADCs and Signal Conversion/I2C_External_Low_SCL: R2.2, U3.6 (LV4); also elsewhere on the board
/ADCs and Signal Conversion/I2C_External_Low_SDA: R1.2, U3.5 (LV3); also elsewhere on the board
/ADCs and Signal Conversion/I2C_Internal_Low_SCL: U4.6 (LV4); also elsewhere on the board
/ADCs and Signal Conversion/I2C_Internal_Low_SDA: U4.5 (LV3); also elsewhere on the board
/ADCs and Signal Conversion/LM35_Alimentatore: U2.10 (A3); also elsewhere on the board
/ADCs and Signal Conversion/LM35_DCDC: U2.8 (A1); also elsewhere on the board
/ADCs and Signal Conversion/LM35_Dissipatore: U2.9 (A2); also elsewhere on the board
/ADCs and Signal Conversion/LM35_PCB: U2.7 (A0); also elsewhere on the board
/ADCs and Signal Conversion/Level_Shift_High_RX: U3.11 (HV2); also elsewhere on the board
/ADCs and Signal Conversion/Level_Shift_High_TX: U3.12 (HV1); also elsewhere on the board
/ADCs and Signal Conversion/Level_Shift_Low_RX: U3.2 (LV2); also elsewhere on the board
/ADCs and Signal Conversion/Level_Shift_Low_TX: U3.1 (LV1); also elsewhere on the board
/ADCs and Signal Conversion/PIN14_Alert_Low_0: U4.1 (LV1); also elsewhere on the board
/ADCs and Signal Conversion/PIN15_Alert_Low_1: U4.2 (LV2); also elsewhere on the board
/ADCs and Signal Conversion/VREF_2_5V: U1.10 (A3); also elsewhere on the board
GND: J3.2, U1.2 (GND), U1.5 (ADDR), U1.7 (A0), U1.8 (A1), U2.2 (GND), U3.4 (GND), U3.9 (GND), U4.4 (GND), U4.9 (GND), U5.2 (GND), U5.6 (GND); also elsewhere on the board
I2C_Internal_High_SCL: U1.3 (SCL), U2.3 (SCL), U4.8 (HV3), U5.4 (SDA)
I2C_Internal_High_SDA: U1.4 (SDA), U2.4 (SDA), U4.7 (HV4), U5.3 (SCL)
unnamed: J3.1, U5.1 (OUT)
PIN14_Alert_High_0: U1.6 (ALRT), U4.12 (HV1)
PIN15_Alert_High_1: U2.6 (ALRT), U4.11 (HV2)
VREF_5V: U5.5 (VCC); also elsewhere on the board

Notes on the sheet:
Tagliare i ponti sotto l' MCP4725

Board: 2 copper layers, 86 parts (0 on the bottom side), 68 nets, no tracks yet.

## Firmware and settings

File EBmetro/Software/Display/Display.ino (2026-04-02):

#include "Setup.h"
#include "Function.h"
#include "Grafica.h"


#include <Arduino.h>
#include <CoreMutex.h>
#include <hardware/gpio.h>
#include <hardware/pwm.h>
#include <hardware/clocks.h>
#include <hardware/pll.h>
#include <hardware/adc.h>

int Menu_Mode_Selected = 0;

volatile float voltage_to_display = 0;
volatile float voltage_pre_zeroing = 0;

uint16_t dimezzamentoFreqDiAggiornamento = 0;

volatile int Rotation = 8;

float readedValue[360] = {0};
uint16_t pixelGraph[360] = {0};

void setup(void){
  //Setup RP2040
  SB(250000);
  delay(1000);

  Initial_Setup();

  //Setup Display
  display_bordoEsterno();
  display_main_initial();
  display_main_select(Encoder_pos_menu);
}

void loop(void){
  if (IRQ_flag) {
    IRQ_flag = false;  // Resetta il flag
    if(getInput()){
      SP("X: ");
      SP(x);
      SP(" Y: ");
      SPL(y);
    }
  }

  if(Encoder_flag){
    Encoder_flag = false;
    if(!Modify_mode){     //////MODALITA NORMALE //////
      switch(Menu_Mode_Selected){
        case 0: //Display
          if(Encoder_pos_menu > 5) Encoder_pos_menu = 0;
          if(Encoder_pos_menu < 0) Encoder_pos_menu = 5;
          display_main_select(Encoder_pos_menu);
          break;
        case 1: //Settings
          if(Encoder_pos_menu > 4) Encoder_pos_menu = 0;
          if(Encoder_pos_menu < 0) Encoder_pos_menu = 4;
          display_settings_select(Encoder_pos_menu);
          break;
        case 2: //Graph
          //Nulla
          break;
        default: break;
      }
    }else{                  //////MODALITA MODIFICA VALORI //////
      switch(Menu_Mode_Selected){
        case 1: //Settings
          switch(Encoder_pos_menu){
              case 1: //Zero E Setup
                Encoder_pos_value = function_settings_zero_clipping(Encoder_pos_value);
                ZERO_E = (float)Encoder_pos_value/10;
                display_settings_select(Encoder_pos_menu);
              break;
              case 0: //Zero B Setup
                Encoder_pos_value = function_settings_zero_clipping(Encoder_pos_value);
                ZERO_B = (float)Encoder_pos_value/10;
                display_settings_select(Encoder_pos_menu);
              break;
            }
          
          
          break;
        default: break;
      }
    }
  }

  if (SW_flag) {
    if(millis() - lastDebounce > 50){
      SW_flag = false;  // Reset SW flag
      if(digitalRead(ENC_SW)){ //SW pressed Correctly
        switch(Menu_Mode_Selected){
          case 0: //################# SW PRESS MENU  ########################## 
            switch(Encoder_pos_menu){
              case 0  ://Settings Button
                Encoder_pos_menu = 3;
                lcd.fillScreen(TFT_BLACK);
                display_bordoEsterno();
                display_settings_init();
                display_settings_select(Encoder_pos_menu);
                Menu_Mode_Selected = 1;
                break;
              case 1: //Hold Button
                valoriHold[2] = valoriHold[1];
                valoriHold[1] = valoriHold[0];
                valoriHold[0] = voltage_to_display;
                
                display_main_hold_value(valoriHold);
                break;
              case 2: //Zero Button
                if(!E_B_State)ZERO_E = voltage_pre_zeroing;
                else ZERO_B = voltage_pre_zeroing;
                break;
              case 3: //On/Off Button
                Motor_State = !Motor_State; 
                digitalWrite(MOTOR_PIN, Motor_State);       // Accende o spegne il motore
                display_main_motor_OnOff(Motor_State);
                break;
              case 4: //UM Button
                /*
                Rotation = Rotation<<1;
                if(Rotation == 16) Rotation = 1;
                valoriHold[0] = Rotation;
                
                display_main_hold_value(valoriHold);
                */
                UnitaMisura_State = !UnitaMisura_State;
                display_main_mode(UnitaMisura_State, E_B_State);
                function_main_adc_mode(E_B_State);
                
                break;
              case 5: //EB Button
                E_B_State = !E_B_State;       // 0 = E, 1= B 
                //digitalWrite(CAPACITOR_PIN, E_B_State ^ Udine);
                display_main_mode(UnitaMisura_State, E_B_State);
                function_main_adc_mode(E_B_State);
                break;
              
              default: break;
            }
            break;
          case 1: ////################# SW PRESS Settings  ##########################
            switch(Encoder_pos_menu){
              case 4: //Home
                Encoder_pos_menu = 3;
                lcd.fillScreen(TFT_BLACK);
                display_bordoEsterno();
                display_main_initial();
                display_main_select(Encoder_pos_menu);
                Menu_Mode_Selected = 0;
              break;
              
              case 3: //Graph
                lcd.fillScreen(TFT_BLACK);
                display_bordoEsterno();
                display_graph_init();
                Menu_Mode_Selected = 2;
              break;

              case 2: //E Multiplier
                E_Reading_Multiplier = !E_Reading_Multiplier;
                display_settings_E_Mul(E_Reading_Multiplier,true);
                function_main_adc_mode(E_B_State);
                break;
              default: break;
              case 1: //Zero E Setup
                Encoder_pos_value =(int)(ZERO_E*10);
                Modify_mode = !Modify_mode;
              break;
              case 0: //Zero B Setup
                Encoder_pos_value =(int)(ZERO_B*10);
                Modify_mode = !Modify_mode;
              break;
            }
            break;

          case 2: ////################# SW PRESS Graph  ##########################
            Encoder_pos_menu = 3;
            lcd.fillScreen(TFT_BLACK);
            display_bordoEsterno();
            display_main_initial();
            display_main_select(Encoder_pos_menu);
            Menu_Mode_Selected = 0;
            break;
          default: break;
        }
      }
    }
  }



  if(TimerUpdateDisplay_Flag){
    TimerUpdateDisplay_Flag = false;
    Serial.println(voltage_to_display); /// PER SCRIVERE A PC
    if(Menu_Mode_Selected == 0){
      display_main_mul(voltage_to_display);
    }
    if(Menu_Mode_Selected == 2){
      if(dimezzamentoFreqDiAggiornamento++ > 1){
        dimezzamentoFreqDiAggiornamento = 0;
        for(int i = 1; i < 360; i++) readedValue[i-1] = readedValue[i];
        readedValue[359] = voltage_to_display;
        float max_value_graph = readedValue[0];
        float min_value_graph = readedValue[0];
        for (int i = 0; i < 360; i++){
          if (readedValue[i] > max_value_graph) {
              max_value_graph = readedValue[i];
          }
          if (readedValue[i] < min_value_graph) {
              min_value_graph = readedValue[i];
          }
        }
        for(int i = 0; i < 360; i++){
          lcd.drawPixel(i+62,pixelGraph[i],TFT_BLACK);
          pixelGraph[i] = 310-map(readedValue[i]*10,min_value_graph*10,max_value_graph*10,20,290);
          lcd.drawPixel(i+62,pixelGraph[i],TFT_YELLOW);
        }
        lcd.setTextDatum(top_left);
        lcd.setTextColor(TFT_YELLOW,TFT_BLACK);
        lcd.setFont(fontList[7]);
        lcd.setTextSize(0.33);
        
        snprintf(bufferV, sizeof(bufferV), "%05.1f", fabs(max_value_graph));
        lcd.drawString((String)bufferV,13,15);
        snprintf(bufferV, sizeof(bufferV), "%05.1f", fabs(min_value_graph));
        lcd.drawString((String)bufferV,13,280);
        lcd.setFont(fontList[1]);
        lcd.setTextSize(0.65);
        lcd.setTextColor(TFT_YELLOW);
        lcd.drawString("+",3,16);
        lcd.drawString("+",3,281);
        lcd.setColor(TFT_BLACK);
        if(max_value_graph<0){
          lcd.drawRect(7,17,1,3);
          lcd.drawRect(7,22,1,3);
        }
        if(min_value_graph<0){
          lcd.drawRect(7,282,1,3);
          lcd.drawRect(7,287,1,3);
        }
      }
    }
  }
}



//Filtro FIR Mean

#define N_TAPPI 256

volatile int16_t sampleBuffer[256]; // Buffer per i campioni
volatile int readIndex = 0;
volatile int circularIndex;


//Gaussian 64
int16_t tappi32[N_TAPPI/8] ={72, 122, 200, 315, 481, 708, 1006, 1380, 1829, 2339, 2888, 3443, 3963, 4404, 4725, 4894, 4894, 4725, 4404, 3963, 3443, 2888, 2339, 1829, 1380, 1006, 708, 481, 315, 200, 122, 72};
int16_t tappi64[N_TAPPI/4] = {92, 112, 135, 163, 194, 230, 271, 317, 369, 426, 489, 559, 634, 714, 800, 890, 985, 1082, 1182, 1283, 1383, 1483, 1579, 1671, 1758, 1837, 1908, 1969, 2019, 2057, 2083, 2097, 2097, 2083, 2057, 2019, 1969, 1908, 1837, 1758, 1671, 1579, 1483, 1383, 1283, 1182, 1082, 985, 890, 800, 714, 634, 559, 489, 426, 369, 317, 271, 230, 194, 163, 135, 112, 92};
int16_t tappi128[N_TAPPI/2] = {349, 355, 361, 367, 373, 379, 386, 392, 398, 404, 410, 416, 422, 428, 434, 440, 446, 452, 458, 464, 469, 475, 481, 486, 491, 497, 502, 507, 512, 517, 522, 527, 532, 536, 541, 545, 550, 554, 558, 562, 565, 569, 572, 576, 579, 582, 585, 588, 590, 593, 595, 597, 599, 601, 603, 604, 606, 607, 608, 609, 609, 610, 610, 610, 610, 610, 610, 609, 609, 608, 607, 606, 604, 603, 601, 599, 597, 595, 593, 590, 588, 585, 582, 579, 576, 572, 569, 565, 562, 558, 554, 550, 545, 541, 536, 532, 527, 522, 517, 512, 507, 502, 497, 491, 486, 481, 475, 469, 464, 458, 452, 446, 440, 434, 428, 422, 416, 410, 404, 398, 392, 386, 379, 373, 367, 361, 355, 349};
int16_t tappi256[N_TAPPI] = {103, 105, 107, 109, 111, 114, 116, 118, 120, 123, 125, 127, 129, 132, 134, 137, 139, 141, 144, 146, 149, 151, 154, 156, 159, 162, 164, 167, 169, 172, 175, 177, 180, 183, 185, 188, 191, 194, 196, 199, 202, 205, 207, 210, 213, 216, 218, 221, 224, 227, 230, 232, 235, 238, 241, 243, 246, 249, 252, 254, 257, 260, 263, 265, 268, 271, 273, 276, 278, 281, 283, 286, 289, 291, 293, 296, 298, 301, 303, 305, 308, 310, 312, 314, 317, 319, 321, 323, 325, 327, 329, 331, 333, 334, 336, 338, 340, 341, 343, 344, 346, 347, 349, 350, 352, 353, 354, 355, 356, 357, 358, 359, 360, 361, 362, 363, 363, 364, 364, 365, 365, 366, 366, 366, 367, 367, 367, 367, 367, 367, 367, 367, 366, 366, 366, 365, 365, 364, 364, 363, 363, 362, 361, 360, 359, 358, 357, 356, 355, 354, 353, 352, 350, 349, 347, 346, 344, 343, 341, 340, 338, 336, 334, 333, 331, 329, 327, 325, 323, 321, 319, 317, 314, 312, 310, 308, 305, 303, 301, 298, 296, 293, 291, 289, 286, 283, 281, 278, 276, 273, 271, 268, 265, 263, 260, 257, 254, 252, 249, 246, 243, 241, 238, 235, 232, 230, 227, 224, 221, 218, 216, 213, 210, 207, 205, 202, 199, 196, 194, 191, 188, 185, 183, 180, 177, 175, 172, 169, 167, 164, 162, 159, 156, 154, 151, 149, 146, 144, 141, 139, 137, 134, 132, 129, 127, 125, 123, 120, 118, 116, 114, 111, 109, 107, 105, 103};
void loop1(){

  if(Sample_flag){
    Sample_flag = false;
    sampleBuffer[readIndex] = adc.getLastConversionResults();
    //Serial.println(sampleBuffer[readIndex]);
    readIndex = (readIndex + 1) % (32*(Rotation));  // Aggiorna readIndex in modo circolare
    
    int64_t tempResult = 0;

    for (int i = 0; i < (32*(Rotation)); i++) {
        circularIndex = (readIndex - i + (32*(Rotation))-1) % (32*(Rotation));
        switch(Rotation){
          case 1:
          tempResult += (int32_t) sampleBuffer[circularIndex] * tappi32[i];
          break;
          case 2:
          tempResult += (int32_t) sampleBuffer[circularIndex] * tappi64[i];
          break;
          case 4:
          tempResult += (int32_t) sampleBuffer[circularIndex] * tappi128[i];
          break;
          case 8: 
          tempResult += (int32_t) sampleBuffer[circularIndex] * tappi256[i];
          break;
        }
      }
    
    if(E_Reading_Multiplier){
      if(!E_B_State) {//E
        voltage_pre_zeroing = ((float)(tempResult >> 16))*10240.0/32768.0; //10240
        voltage_to_display = voltage_pre_zeroing - ZERO_E;
      }//B
      else {
        voltage_pre_zeroing = ((float)(tempResult >> 16))*10240.0/32768.0; //2560 Old
        voltage_to_display = voltage_pre_zeroing - ZERO_B;
      }
    } 
    else {
      if(!E_B_State) {//E
        voltage_pre_zeroing = ((float)(tempResult >> 16))*1024.0/32768.0; //1024
        voltage_to_display = voltage_pre_zeroing - ZERO_E;
      }//B
      else {
        voltage_pre_zeroing = ((float)(tempResult >> 16))*1024.0/32768.0; //256 Old
        voltage_to_display = voltage_pre_zeroing - ZERO_B;
      }
    }
    
  }

}

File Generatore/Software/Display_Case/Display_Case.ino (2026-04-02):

#include <Arduino.h>
#include <LovyanGFX.hpp>
#include <SPI.h>
#include <Adafruit_ADS1X15.h>
#include <Wire.h>
#include <RPi_Pico_TimerInterrupt.h>
#include "Setup.h"
#include "Menu.h"
#include "Ramp.h"
#include "Wire.h"
#include "Comunication.h"
#include "Settings.h"

int16_t x = 0, y = 0,z = 0; // Coordinate del touchscreen

int Menu_Mode_Selected = 0;

uint8_t data_recived[6] ={0,0,0,0,0,0};

void setup(void){
  Serial.begin(115200);
  delay(1000);

  Initial_Setup();
  if (!com_init_serialcom(19200)) {
    SPL("Failed to initialize Serial1 (Case)");
    while (1);
  }
  com_case_send_off();
  SPL("Serial1 (Case) successfully Initialized");

  //SETUP DISPLAY
  menu_display_bordoEsterno();
  menu_display_initial();
  menu_display_rect(Encoder_pos_menu);
}

void loop(void){
  if (IRQ_flag) {
    IRQ_flag = false;  // Resetta il flag
    // Leggi le coordinate dal touchscreen
    if(getInput()){
    // Stampa le coordinate
    Serial.print("X: ");
    Serial.print(x);
    Serial.print(" Y: ");
    Serial.println(y);
    }
  }
  
  if(Encoder_flag){
    Encoder_flag = false;
    if(!Modify_mode){     //////MODALITA NORMALE //////
      switch(Menu_Mode_Selected){
        case 0: //MENU
          if(Encoder_pos_menu > 2) Encoder_pos_menu = 0;
          if(Encoder_pos_menu < 0) Encoder_pos_menu = 2;
          menu_display_rect(Encoder_pos_menu);
          break;
        case 1: //RAMP
          if(Encoder_pos_menu > 9) Encoder_pos_menu = 0;
          if(Encoder_pos_menu < 0) Encoder_pos_menu = 9;
          ramp_display_select(Encoder_pos_menu);
          break;
        case 2: //Wire
          if(Encoder_pos_menu > 3) Encoder_pos_menu = 0;
          if(Encoder_pos_menu < 0) Encoder_pos_menu = 3;
          wire_display_select(Encoder_pos_menu);
          break;
        case 3: //Settings
          if(Encoder_pos_menu > 3) Encoder_pos_menu = 0;
          if(Encoder_pos_menu < 0) Encoder_pos_menu = 3;
          settings_display_select(Encoder_pos_menu);
          break;

        default: break;
      }
    }else{                  //////MODALITA MODIFICA VALORI //////
      switch(Menu_Mode_Selected){
        case 1: //RAMP 
          Encoder_pos_value = ramp_var_clipping(Encoder_pos_menu,Encoder_pos_value);
          ramp_display_select(Encoder_pos_menu);
          break;  
        case 2: //WIRE
          Encoder_pos_value = wire_var_clipping(Encoder_pos_value);
          wire_display_select(Encoder_pos_menu);
          break;
        case 3: //Settings
          Encoder_pos_value = settings_var_clipping(Encoder_pos_value);
          settings_display_select(Encoder_pos_menu);
          break;
        
        default: break;
      }
    }
  }

  if (SW_flag) {
    SW_flag = false;  // Reset SW flag
    switch(Menu_Mode_Selected){
      case 0: //################# SW PRESS MENU  ########################## 
        switch(Encoder_pos_menu){
          case 0  ://RAMP Button
            Encoder_pos_menu = 0;                         //Reset Encoder
            Menu_Mode_Selected = 1;                       //Seleziona la Pagina Ramp
            lcd.fillScreen(TFT_BLACK);                    //Reset schermo
            menu_display_bordoEsterno();                  //Stampa il Bordo bianco
            TimerUpdateDisplay.enableTimer();             //Avvio timer aggiornamento display
            ramp_display_initial();                       //Avvia la procedura iniziale
            ramp_display_handle_selected(selected_handle);//Scrivo Handle 
            ramp_wire_display_status(0);                  //Sicuramente partirà da Stopped
            ramp_display_select(0);                       //Seleziona la posizione home
            com_case_send_on();                           //Richiedi al case di inviare i dati
            break;
          case 1: //WIRE Button
            Encoder_pos_menu = 0;                     //Reset Encoder
            Menu_Mode_Selected = 2;                   //Seleziona la Pagina Wire
            lcd.fillScreen(TFT_BLACK);                //Reset schermo
            menu_display_bordoEsterno();              //Stampa il Bordo binco
            TimerUpdateDisplay.enableTimer();         //Avvio timer aggiornamento display
            wire_display_initial();                   //Avvia la procedura iniziale
            ramp_wire_display_status(0);              //Sicuramente partirà da Stopped
            wire_display_select(0);                   //Seleziona la posizione home
            com_case_send_on();                         //Richiedi al case di inviare i dati
            break;
          case 2: //SETTINGS Button
            Encoder_pos_menu = 1;                     //Reset Encoder
            Menu_Mode_Selected = 3;                   //Seleziona la Pagina Wire
            lcd.fillScreen(TFT_BLACK);                //Reset schermo
            menu_display_bordoEsterno();
            settings_display_initial();
            settings_display_select(1);
            settings_display_print_maxmin(8888,8888);
            break;
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
